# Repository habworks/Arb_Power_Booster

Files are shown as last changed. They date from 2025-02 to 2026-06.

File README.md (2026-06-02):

# Arbitrary Power Booster
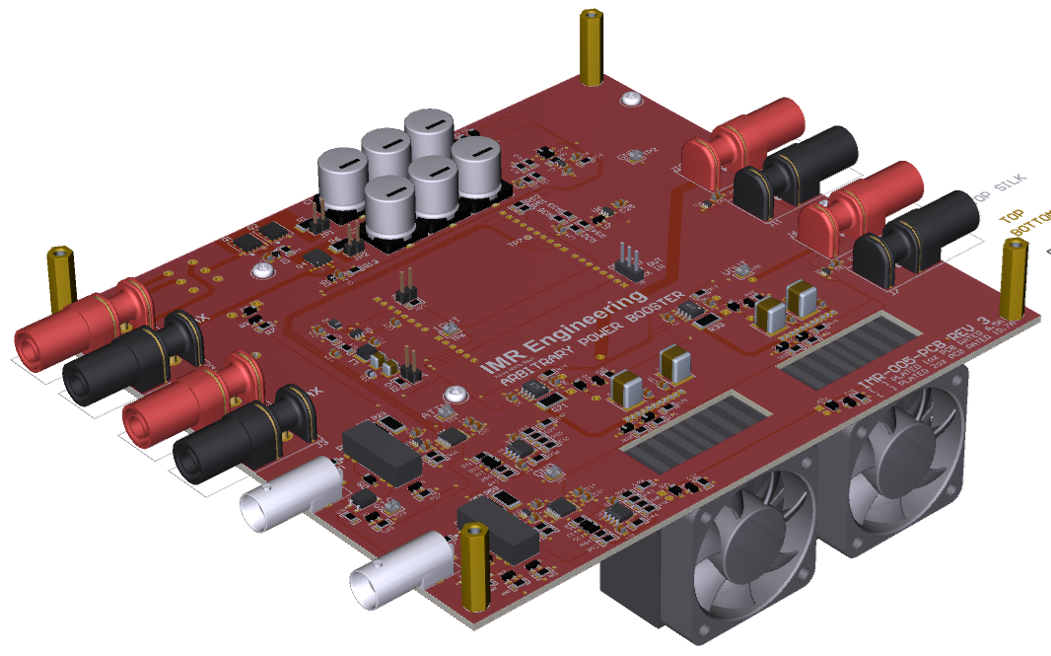
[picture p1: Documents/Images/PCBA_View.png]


## Quick Visual Links:
See [Video Demo](https://imrengineeringcom-my.sharepoint.com/:v:/g/personal/hab_collector_imrengineering_com/ETz-QbAvxjtEm_Lhyh-R2pUBUKSNs67Pcy3YFl8mtPB_mw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) from IMR Cloud<br>
See [User Manual & Technical Specification](https://imrengineeringcom-my.sharepoint.com/:b:/g/personal/hab_collector_imrengineering_com/EVBAl45Asp9Jv4Ho5CQpJLwBBzy_O8o_hFsLN9PBJ4WJYw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) from IMR Cloud<br>
See [Schematics PCB and BOM](https://imrengineeringcom-my.sharepoint.com/:b:/g/personal/hab_collector_imrengineering_com/EVWHgYOxN1xJqR7aqiF_OPgBgC4Y5v372JjiHFJdWcHM8w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) from IMR Cloud<br>

## Project Features:
Based on an ARM Cortex M7 two channel power amplication for driving heavy loads according to real world inputs.  Designed as a test equipment the device measures in True RMS with settable limits for power.  Features include:<br>
Hardware:
- 25W continuous per channel  
- Wide operating voltage -14V < Vo < +14V  
- Precision Absolute Value Divider  
- SSR Input Protection  
- Selectable Input Impedance  
- +/- Inrush Current Limiter  

Firmware:
- FreeRTOS OS  
- UI Touch Interface 242x480  
- True RMS  
- PID output control  
- Fault Tolerant  
- Smart Cooling  

Hardware and Firmware 100% designed by:<br>
Hab Collector<br>
Principal Engineer<br>
IMR Engineering, LLC<br>

## Project Folders:
| Folder | Description |
|---|---|
| Demo | URL to demo - just use the link provided above|
| Documents | UMTS, Images, and reference material|
| Firmware/ArbPwrBooster_App| Application Firmware|
| Hardware | Hardware Design in Circuit Studio: Schematics, PCB, BOM|
| Simulate | Spice Modle Simulation (LT Spice)|
| TestResults | Measured test results to support specification|

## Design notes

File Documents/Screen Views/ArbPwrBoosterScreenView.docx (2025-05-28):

ARBITRARY POWER BOOSTER SCREEN VIEWS

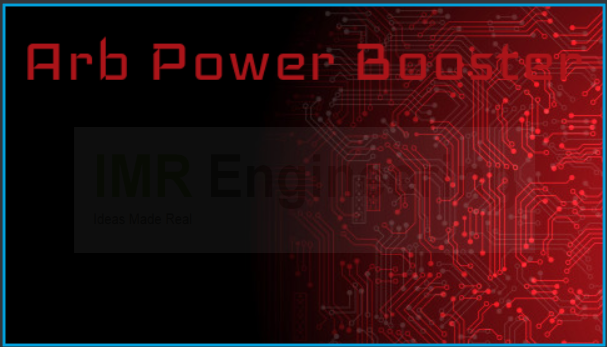
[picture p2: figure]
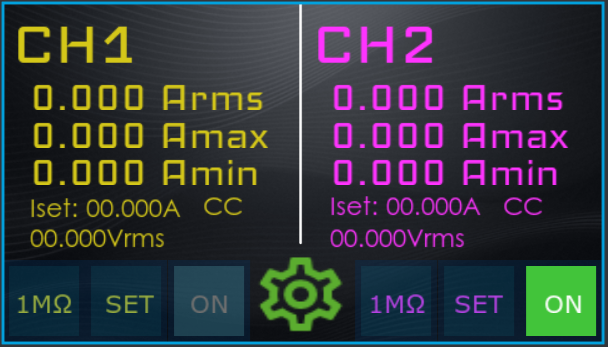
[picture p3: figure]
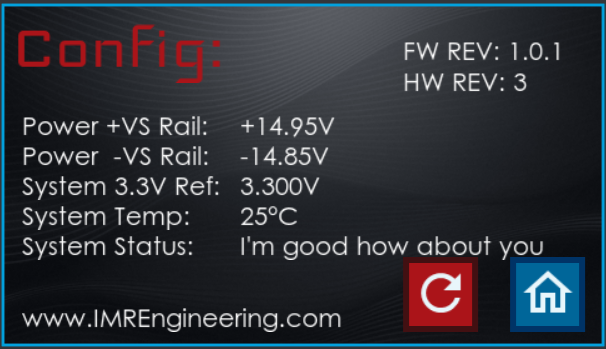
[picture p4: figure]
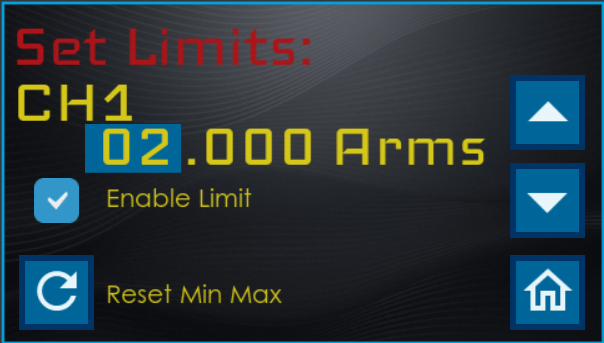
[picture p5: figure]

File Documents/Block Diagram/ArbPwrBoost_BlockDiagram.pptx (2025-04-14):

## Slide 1

MAIN PWR
RELAY

-15V INPUT

±15V PWR
MONITOR

- LAB SUPPLY 1
-15V NOMINAL

INRUSH
LIMITER

-20V INRUSH CURRENT LIMITER

BULK STORAGE

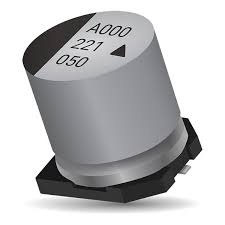
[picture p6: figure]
Aluminum Electrolytic Capacitors ...

-20V SWITCHED SUPPLY RAIL

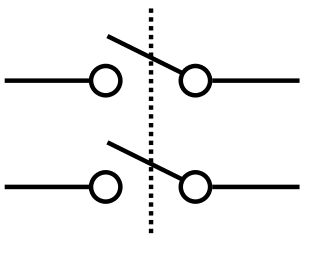
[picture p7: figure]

+15V INPUT

+ LAB SUPPLY 2
+15V NOMINAL

+20V INRUSH CURRENT LIMITER

+20V SWITCHED SUPPLY RAIL

5V REGULATOR
800mA

MAIN SUPPLY RAIL ENABLE

5V SYSTEM PWR

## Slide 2

CH1 IN

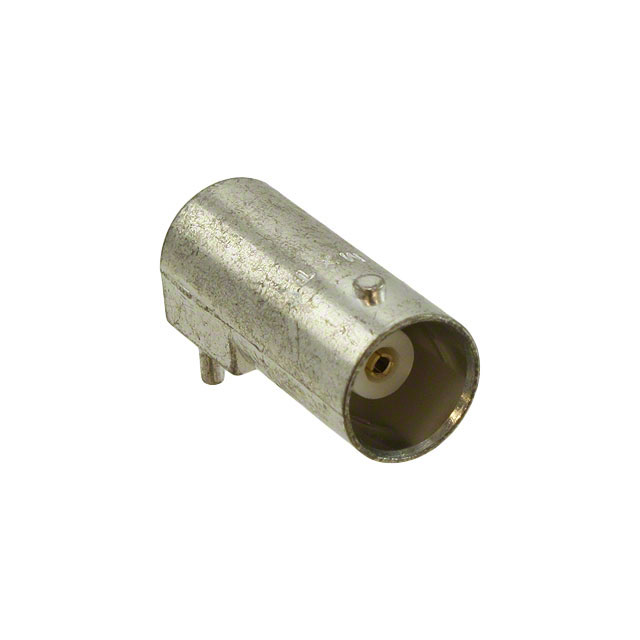
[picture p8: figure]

INPUT Z
SWITCHED
50Ω / 1MΩ

Av = 1

ADC ARB IN 1

DIGITAL
VOLTAGE
DIVIDER

Av = 1

+15V MON

Current
Boost

CURRENT
SENSE

OUTPUT
DISCONNECT

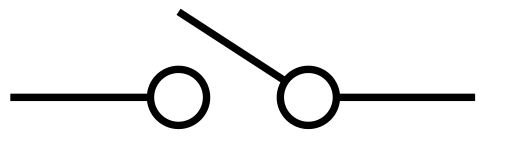
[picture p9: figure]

CH1 OUT

ADC – IMON 1

I2C

-15V MON

ADC

UI INTERFACE MODULE
STM32F746G-DISCO

ADC

3.3V SYSTEM PWR

CURRENT
SENSE

5V SYSTEM PWR

ADC – IMON 2

ADC ARB IN 2

Av = 1

DIGITAL
VOLTAGE
DIVIDER

I2C

INPUT Z
SWITCHED
50Ω / 1MΩ

Av = 1

Current
Boost

OUTPUT
DISCONNECT

CH2 IN

CH2 OUT

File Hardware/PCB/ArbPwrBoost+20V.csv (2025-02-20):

Index | X (mm) | Y (mm) | Arc Angle (Neg = CW)
0 | 74 | 159
1 | 144 | 159
2 | 144 | 17
3 | 55 | 17
4 | 50 | 17
3 | 29 | 17
5 | 29 | 38
6 | 125 | 38
7 | 125 | 61
8 | 29 | 61
9 | 29 | 79
10 | 50 | 79
11 | 55 | 79
12 | 125 | 79
13 | 125 | 147
14 | 74 | 147

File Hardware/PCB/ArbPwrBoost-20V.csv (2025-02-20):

Index | X (mm) | Y (mm) | Arc Angle (Neg = CW)
0 | 120 | 140
1 | 15 | 140
2 | 15 | 1
3 | 64 | 1
4 | 120 | 1
5 | 120 | 16
6 | 55 | 16
9 | 50 | 16
10 | 27.5 | 16
11 | 27.5 | 39
12 | 120 | 39
13 | 120 | 59.8
14 | 119.8 | 60
15 | 27.5 | 60
16 | 27.5 | 124
17 | 120 | 124

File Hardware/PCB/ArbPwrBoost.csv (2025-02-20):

Index | X (mm) | Y (mm) | Arc Angle (Neg = CW)
0 | 120 | 140
1 | 15 | 140
2 | 15 | 1
3 | 64 | 1
4 | 120 | 1
5 | 120 | 16
6 | 55 | 16
9 | 50 | 16
10 | 27.5 | 16
11 | 27.62 | 39
12 | 120 | 39
13 | 120 | 59.8
14 | 119.8 | 60
15 | 27.62 | 60
16 | 27.62 | 124
17 | 120 | 124

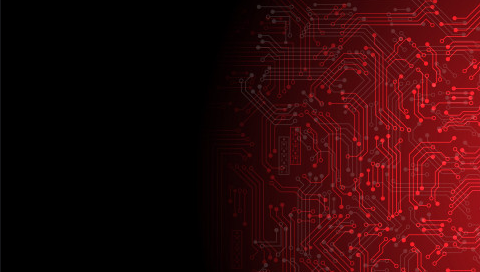
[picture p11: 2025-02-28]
Firmware/ArbPwrBooster_App/TouchGFX/assets/images/CircuitTrace_480x272.png

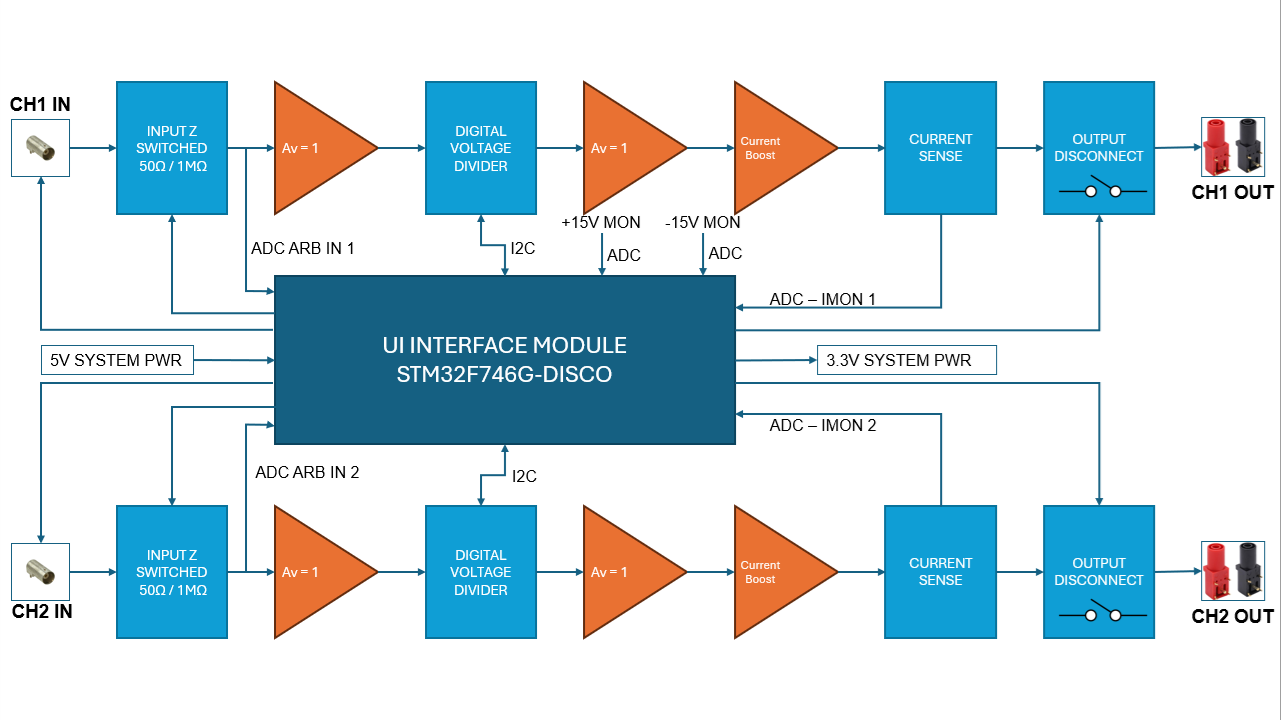
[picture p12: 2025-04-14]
Documents/Block Diagram/Block_PG2.png

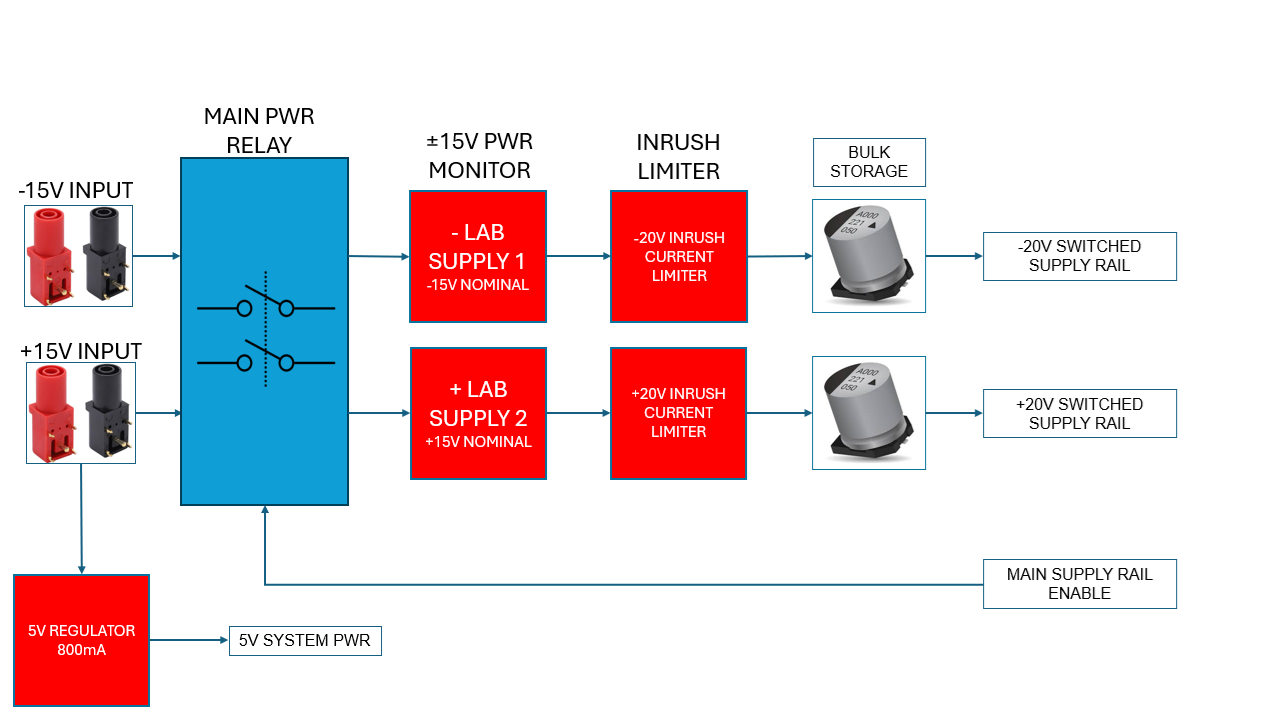
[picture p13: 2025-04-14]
Documents/Block Diagram/Block_PG1.png

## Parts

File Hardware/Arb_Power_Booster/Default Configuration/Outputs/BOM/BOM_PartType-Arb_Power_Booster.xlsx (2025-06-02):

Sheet: Part List Report
 |  | PROTOTYPE BOM |  |  | Arbitrary Power Booster
 |  | Source Data From: | Arb_Power_Booster.PrjPcb |  | Company Part Number: | IMR-005-SCH
 |  | Project: | Arb_Power_Booster.PrjPcb |  | PCB Revision: | 4
 |  | Variant: | None |  | Engineer: | Hab S Collector
 |  | Report Date: | 5/29/2025 | 9:01:38 AM
 |  | Print Date: | 2025-05-29 | 9:02:41
# | Quantity | LibRef | Description | Designator | MFG | MFG_PN | Supplier 1 | Supplier Part Number 1 | Unit Price | TOTAL
1 | 6 | CAP_330UF_50V_ALE | CAP ALE 330UF 20% 50V SMD | C1, C2, C3, C9, C10, C11 | EEV-FK1H331Q | Panasonic Electronic | DigiKey | PCE3475CT-ND | 1.41 | $8.46
2 | 3 | CAP_SMD_10UF_50V_0805 | CAP CER 10UF 50V X5R 0805 | C4, C12, C16 | Murata Electronics | GRM21BR61H106KE43L | DigiKey | 490-18663-1-ND | .28 | $0.84
3 | 30 | CAP_SMD_0.1UF_50V_0805 | CAP CER 0.1UF 50V X7R 0805 | C5, C6, C7, C8, C13, C17, C18, C19, C20, C21, C22, C23, C24, C25, C26, C27, C29, C33, C34, C35, C36, C37, C38, C39, C40, C41, C43, C44, C45, C46 | KYOCERA AVX | KGM21NR71H104KT | DigiKey | 478-KGM21NR71H104KTCT-ND | .1 | $3.00
4 | 1 | CAP_SMD_68PF_50V_0805 | CAP CER 68PF 50V X7R 0805 | C14 | KEMET | C0805C680K5RACAUTO | DigiKey | 399-C0805C680K5RACAUTOCT-ND | .24 | $0.24
5 | 2 | CAP_SMD_47UF_16V_1210 | CAP CER 47UF 50V X5R 1210 | C15, C48 | Murata Electronics | GRM32ER60J476ME20L | DigiKey | 490-1887-1-ND | .28 | $0.56
6 | 2 | CAP_SMD_1UF_50V_0805 | CAP CER 1UF 50V X7R 0805 | C28, C42 | KYOCERA AVX | 08055C105K4T2A | DigiKey | 478-KAM21KR71H105KUCT-ND | .27 | $0.54
7 | 4 | CAP_SMD_100UF_25V_SMD | CAP CER 100UF 25V X7S SMD | C30, C31, C32, C47 | Murata Electronics | KCM55WC71E107MH13L | DigiKey | 490-KCM55WC71E107MH13LCT-ND | 5.68 | $22.72
8 | 2 | DIODE_ZENER_MMSZ5239BS-7-F | DIODE ZENER 9.1V 200MW SOD323 | D1, D5 | Diodes Inc | MMSZ5239BS-7-F | DigiKey | MMSZ5239BS-FDICT-ND | .18 | $0.36
9 | 17 | DIODE_1N4148W-7-F | RELAY REED SPDT 250MA 5V | D2, D3, D7, D9, D10, D11, D12, D13, D14, D15, D16, D17, D18, D19, D20, D21, D22 | Diodes Inc | 1N4148W-7-F | DigiKey | 1N4148W-FDICT-ND | .16 | $2.72
10 | 2 | DIODE_SCHOTTKY_1N5819HW-7-F | DIODE SCHOTTKY 40V 1A SOD123 | D4, D8 | Diodes Inc | 1N5819HW-7-F | DigiKey | 1N5819HW-FDICT-ND | .25 | $0.50
11 | 1 | DIODE_SCHOTTKY_B240S1F-7 | DIODE SCHOTTKY 40V 2A SOD123F | D6 | Diodes Inc | B240S1F-7 | DigiKey | B240S1F-7DICT-ND | .25 | $0.25
12 | 2 | FAN_AFB0405LA-A | FAN AXIAL 40X10MM BALL 5VDC WIRE | FAN1, FAN2 | Delta Electronicis | AFB0405LA-A | DigiKey | 603-2014-ND | 7.31 | $14.62
13 | 1 | FERRITE_2508053017Y3 | FERRITE BEAD 300 OHM 0805 1LN | FB1 | Fair-Rite | 2508053017Y3 | DigiKey | 1934-1474-1-ND | .10 | $0.10
14 | 2 | HEATSINK_CS9464020BP | Heat Sink Aluminum Top Mount | HS1, HS2 | Cooling Source | CS9464020BP | DigiKey | 4165-CS9464020BP-ND | 3.41 | $6.82
15 | 4 | CONN_PANOMA_73099-2 | CONN 4mm Banana Socket Right Angle PCB RED | J1, J4, J6, J10 | Pomona | 73099-2 | DigiKey | 501-73099-2-ND | 10.39 | $41.56
16 | 4 | CONN_PANOMA_73099-0 | CONN 4mm Banana Socket Right Angle PCB BLK | J2, J3, J7, J11 | Pomona | 73099-0 | DigiKey | 501-73099-0-ND | 10.39 | $41.56
17 | 2 | CONN_MOLEX_0731713150 | CONN BNC RCPT R/A 50 OHM PCB | J5, J9 | Molex | 0731713150 | DigiKey | WM20430-ND | 1.40 | $2.80
18 | 1 | CONN_HEADER_3P_100MIL_VERT | CONN HEADER VERT 3POS 2.54MM | J8 | Sullins Connector Solutions | PREC003SFAN-RC | Digi-Key | S1212EC-03-ND | .07 | $0.07
19 | 4 | CONN_JUMPER_2P_100MIL_VERT | CONN HEADER VERT 2POS 2.54MM | JP1, JP2, JP3, JP4 | Sullins Connector Solutions | PREC002SFAN-RC | Digi-Key | S1212EC-02-ND | .07 | $0.28
20 | 1 | INDUCTOR_SRN4018TA-6R8M | FIXED IND 6.8UH 1.7A 98 MOHM SMD | L1 | Bourns Inc. | SRN4018TA-6R8M | DigiKey | SRN4018TA-6R8MCT-ND | .48 | $0.48
21 | 2 | LED_RED_LTST-C170EKT | LED RED CLEAR SMD | LED1, LED2 | Diodes Inc | LTST-C170EKT | DigiKey | 160-1178-1-ND | .18 | $0.36
22 | 8 | MECHANICAL_SCREW_M3X6_PAN_HEAD | SCREW M3X6 PAN HEAD SS | MECH1, MECH2, MECH3, MECH4, MECH9, MECH10, MECH11, MECH12 | APM Hexseal | RM3X6MM 2701 | DigiKey | 335-1156-ND | .58 | $4.64
23 | 4 | MECHANICAL_STANDOFF_M3X20 | HEX STANDOFF M3 BRASS 20MM | MECH5, MECH6, MECH7, MECH8 | Keystone Electronics | 24407 | DigiKey | 36-24407-ND | 1.36 | $5.44
24 | 2 | MOSFET_PCH_DMP6050SPS-13 | MOSFET P-CH 60V 5.7A PWRDI5060-8 | Q1, Q2 | Diodes Inc | DMP6050SPS-13 | DigiKey | DMP6050SPS-13DICT-ND | 1.07 | $2.14
25 | 7 | MOSFET_NCH_2N7002-7-F | MOSFET N-CH 60V 115MA SOT23-3 | Q3, Q7, Q8, Q9, Q10, Q11, Q12 | Diodes Inc | 2N7002-7-F | DigiKey | 2N7002-FDICT-ND | .20 | $1.40
26 | 1 | MOSFET_NCH_DMNH6042SPDQ-13 | MOSFET NCH 60V 5.7A POWERDI | Q4 | Diodes Inc | DMNH6042SPDQ-13 | DigiKey | DMNH6042SPDQ-13DICT-ND | 1.36 | $1.36
27 | 2 | MOSFET_NCH_DMN3023L-7 | MOSFET N-CH 30V 6.2A SOT23-3 | Q5, Q6 | Diodes Inc | DMN3023L-7 | DigiKey | DMN3023L-7DICT-ND | .48 | $0.96
28 | 2 | RES_SMD_0_2512_1W_1% | RES SMD 0 OHM 1% 1W 2512 | R1, R6 | Yageo | RC2512JK-070RL | DigiKey | YAG1232CT-ND | .2 | $0.40
29 | 18 | RES_SMD_10K_0805_1/4W_1% | RES SMD 10K OHM 1% 1/4W 0805 | R2, R7, R8, R25, R27, R30, R31, R32, R37, R38, R45, R51, R52, R63, R65, R66, R67, R69 | Yageo | RC0805FR-7W10KL | DigiKey | 13-RC0805FR-7W10KLCT-ND | .10 | $1.80
30 | 12 | RES_SMD_10K_0805_1/8W_0.1% | RES SMD 10K OHM 0.1% 1/8W 0805 | R3, R11, R42, R43, R46, R47, R53, R54, R61, R62, R64, R72 | Yageo | RP0805BRD0710KL | DigiKey | 13-RP0805BRD0710KLCT-ND | .16 | $1.92
31 | 2 | RES_SMD_47K_0805_1/8W_1% | RES SMD 47K OHM 1% 1/8W 0805 | R4, R13 | Yageo | RC0805FR-1347KL | DigiKey | 13-RC0805FR-1347KLCT-ND | .1 | $0.20
32 | 2 | RES_SMD_1.24K_0805_1/8W_0.1% | RES SMD 1.24K OHM 0.1% 1/8W 0805 | R5, R15 | Yageo | RT0805BRD071K24L | DigiKey | YAG1809CT-ND | .16 | $0.32
33 | 1 | RES_SMD_2.1K_0805_1/8W_0.1% | RES SMD 2.1K OHM 0.1% 1/8W 0805 | R9 | Yageo | RT0805BRD072K1L | DigiKey | YAG1852CT-ND | .16 | $0.16
34 | 8 | RES_SMD_0_0805_1/8W_1% | RES SMD 0 OHM 1% 1/8W 0805 | R10, R18, R19, R24, R26, R28, R36, R50 | Yageo | RC0805JR-070RL | DigiKey | 311-0.0ARCT-ND | .1 | $0.80
35 | 1 | RES_SMD_1.0K_0805_1/8W_0.1% | RES SMD 1.0K OHM 0.1% 1/8W 0805 | R12 | Yageo | RT0805BRD071KL | DigiKey | YAG1820CT-ND | .16 | $0.16
36 | 1 | RES_SMD_100K_0805_1/4W_1% | RES SMD 100K OHM 1% 1/4W 0805 | R14 | Yageo | RC0805FR-07100KL | DigiKey | 311-100KCRCT-ND | .13 | $0.13
37 | 1 | RES_SMD_1.0K_0805_1/8W_1% | RES SMD 1.0K OHM 1% 1/8W 0805 | R16 | Yageo | RC0805FR-071KL | DigiKey | 311-1.00KCRCT-ND | .1 | $0.10
38 | 1 | RES_SMD_12.4K_0805_1/8W_1% | RES SMD 12.4K OHM 1% 1/8W 0805 | R17 | Yageo | RC0805FR-0712K4L | DigiKey | 311-12.4KCRCT-ND | .10 | $0.10
39 | 2 | RES_SMD_300_0805_1/8W_1% | RES SMD 300 OHM 1% 1/8W 0805 | R20, R29 | Yageo | RC0805FR-07300RL | DigiKey | 311-300CRCT-ND | .1 | $0.20
40 | 2 | RES_SMD_1M_0805_1/4W_1% | RES SMD 1K OHM 1% 1/4W 0805 | R21, R57 | Yageo | RC0805FR-7W1ML | DigiKey | 13-RC0805FR-7W1MLCT-ND | .10 | $0.20
41 | 4 | RES_SMD_100_0805_3.5W_1% | RES SMD 100 OHM 1% 3.5W 2512 | R22, R23, R58, R59 | Ohmite | ALN2512F100RE-1 | DigiKey | 273-ALN2512F100RE-1CT-ND | 1.50 | $6.00
42 | 1 | RES_SMD_1.5K_0805_1/8W_0.1% | RES SMD 1.5K OHM 0.1% 1/8W 0805 | R33 | Yageo | RT0805BRD071K5L | DigiKey | YAG1814CT-ND | .16 | $0.16
43 | 1 | RES_SMD_4.7K_0805_1/8W_0.1% | RES SMD 4.7K OHM 0.1% 1/8W 0805 | R34 | Yageo | RT0805BRD074K7L | DigiKey | YAG1919CT-ND | .16 | $0.16
44 | 1 | RES_SMD_90.9_0805_1/8W_1% | RES SMD 90.9 OHM 1% 1/8W 0805 | R35 | Yageo | RC0805FR-0790R9L | DigiKey | 311-90.9CRCT-ND | .1 | $0.10
45 | 2 | RES_SMD_0.0065_2512_2W_1% | RES SMD 0.0065 OHM 1% 2W 2512 | R39, R71 | Vishay Dale | WSL25126L500FEA18 | DigiKey | 541-WSL25126L500FEA18CT-ND | 1.76 | $3.52
46 | 2 | RES_SMD_3.0K_0805_1/8W_0.1% | RES SMD 3.0K OHM 0.1% 1/8W 0805 | R40, R49 | Yageo | RT0805BRD073KL | DigiKey | YAG1891CT-ND | 0.16 | $0.32
47 | 2 | RES_SMD_4.99K_0805_1/8W_1% | RES SMD 4.99K OHM 1% 1/8W 0805 | R41, R48 | Yageo | RC0805FR-134K99L | DigiKey | 13-RC0805FR-134K99LCT-ND | .1 | $0.20
48 | 2 | RES_SMD_2.49K_0805_1/8W_1% | RES SMD 2.49K OHM 1% 1/8W 0805 | R44, R56 | Yageo | RC0805FR-132K49L | DigiKey | 13-RC0805FR-132K49LCT-ND | .1 | $0.20
49 | 2 | RES_SMD_5.0K_0805_1/8W_0.1% | RES SMD 5.0K OHM 0.1% 1/8W 0805 | R55, R68 | Yageo | AT0805BRD075KL | DigiKey | 13-AT0805BRD075KLCT-ND | .56 | $1.12
50 | 2 | RES_SMD_4.7K_0805_1/8W_1% | RES SMD 4.7K OHM 1% 1/8W 0805 | R60, R70 | Yageo | RC0805FR-134K7L | DigiKey | 13-RC0805FR-134K7LCT-ND | .1 | $0.20
51 | 2 | RES_SMD_10_0805_1/8W_1% | RES SMD 10 OHM 1% 1/8W 0805 | R73, R74 | Yageo | RC0805FR-1310RL | DigiKey | 13-RC0805FR-1310RLCT-ND | .1 | $0.20
52 | 1 | RELAY_AZ733-2AE-5DE | RELAY REED SPDT 250MA 5V | REL1 | American Zettler | AZ733-2AE-5DE | DigiKey | 3385-AZ733-2AE-5DE-nd | 2.18 | $2.18
53 | 2 | RELAY_HE721C0500 | RELAY REED SPDT 250MA 5V | REL2, REL4 | Littlefuse | HE721C0500 | DigiKey | HE112-ND | 3.77 | $7.54
54 | 2 | RELAY_G5LE-1-36 DC5 | RELAY GEN PURPOSE SPDT 10A 5V | REL3, REL5 | Omron | G5LE-1-36 DC5 | DigiKey | G5LE-1-36DC5-ND | 1.24 | $2.48
55 | 2 | RELAY_TLP170AM(TPL,E | SSR RELAY SPST-NO 700MA 0-60V | REL6, REL7 | Toshiba | TLP170AM(TPL,E | DigiKey | 264-TLP170AM(TPLECT-ND | 1.33 | $2.66
56 | 1 | SWITCH_SLW-12689-4A-N-D | SWITCH SLIDE SPDT 300MA 50V | SW1 | Same Sky | SLW-12689-4A-N-D | DigiKey | 2223-SLW-12689-4A-N-D-ND | .48 | $0.48
57 | 1 | SWITCH_EVQ-Q2U02W | SWITCH TACTILE SPST-NO 0.02A 15V | SW2 | American Zettler | EVQ-Q2U02W | DigiKey | P12954SCT-ND | .25 | $0.25
58 | 6 | CONN_TEST_POINT_S1751-46R | PCB TEST POINT CONNECT | TP1, TP2, TP3, TP4, TP5, TP6 | Harwin Inc | S1751-46R | Digi-Key | 952-1478-1-ND | .28 | $1.68
59 | 1 | IC_TPS54202DDCR | IC REG BUCK ADJ 2A SOT23 | U1 | Texas Instruments | TPS54202DDCR | Digi-Key | 296-TPS54202DDCRCT-ND | .97 | $0.97
60 | 3 | OPAMP_TLV9351IDCKR | IC OPAMP GP 3.5MHZ 350uV C70-5 | U2, U3, U10 | Texas Instruments | TLV9351IDCKR | DigiKey | 296-TLV9351IDCKRCT-ND | .49 | $1.47
61 | 2 | IC_MCP45HV51-104E/ST | IC DGT POT 100KOHM 256TP 14TSSOP | U4, U11 | Microchip | MCP45HV51-104E/ST | DigiKey | MCP45HV51-104E/ST-ND | 2.00 | $4.00
62 | 2 | IC_SN74LVC1G14DCKR | IC INVERT SCHMITT 1CH 1IN SC70-5 | U5, U16 | Texas Instruments | SN74LVC1G14DCKR | DigiKey | 296-11608-1-ND | .10 | $0.20
63 | 1 | OPAMP_LMP2011MFX/NOPB | IC OPAMP GP 3MHZ .12uV CIRCUIT SOT23-5 | U6 | Texas Instruments | LMP2011MFX/NOPB | DigiKey | LMP2011MFX/NOPBCT-ND | 2.33 | $2.33
64 | 1 | IC_LM4041CYM3-ADJ-TR | IC VREF SHUNT ADJ 0.5% SOT23-3 | U7 | Microchip | LM4041CYM3-ADJ-TR | DigiKey | 576-1049-1-ND | .39 | $0.39
65 | 2 | IC_INA282AIDR | IC CURRENT SENSE 0.4% 50V/V SOIC-8 | U8, U13 | Texas Instruments | INA282AIDR | DigiKey | 296-27820-1-ND | 4.13 | $8.26
66 | 1 | MODULE_STM32F746G-DISCO | DISCOVERY STM32 F7 EVAL BRD | U9 | ST Microlectronics | STM32F746G-DISCO | DigiKey | 497-15680-5-ND | 57.50 | $57.50
67 | 2 | OPAMP_OPA549S | IC OPAMP POWER 1 CIRC 11PWRPACK | U12, U17 | Texas Instruments | OPA549S | DigiKey | OPA549S-ND | 26.94 | $53.88
68 | 2 | OPAMP_TLV9302IDR | IC OPAMP GP 2 CIRCUIT 8SOIC | U14, U15 | Texas Instruments | TLV9302IDR | DigiKey | 296-53513-1-ND | .66 | $1.32
Approved |  |  |  |  | Notes |  |  | Bill of Cost (Unit Buy): |  | $331.04

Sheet: Project Information
Project Full Path | C:\IMR_Projects\IMR\Arb_Power_Booster\Hardware\Arb_Power_Booster\Arb_Power_Booster.PrjPcb
Project Filename | Arb_Power_Booster.PrjPcb
Variant Name | None
Data-Source Filename | Arb_Power_Booster.PrjPcb
Data-Source Full Path | C:\IMR_Projects\IMR\Arb_Power_Booster\Hardware\Arb_Power_Booster\Arb_Power_Booster.PrjPcb
Title | Arbitrary Power Booster
Total Quantity | 223
Report Time | 9:01:38 AM
Report Date | 5/29/2025
Report Date & Tine | 5/29/2025 9:01:38 AM
Output Name | BOM_PartType
Output Type | BOM_PartType
Output Generator Name | BOM
Output Generator Description | Bill of Materials
Total Actual Price | <Parameter TotalActualPrice not found>
Total Target Price | <Parameter TotalTargetPrice not found>

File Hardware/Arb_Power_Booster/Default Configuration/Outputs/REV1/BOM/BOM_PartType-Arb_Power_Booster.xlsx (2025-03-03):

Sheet: Part List Report
 |  | PROTOTYPE BOM |  |  | Arbitrary Power Booster
 |  | Source Data From: | Arb_Power_Booster.PrjPcb |  | Company Part Number: | IMR-005-SCH
 |  | Project: | Arb_Power_Booster.PrjPcb |  | PCB Revision: | 1
 |  | Variant: | None |  | Engineer: | Hab S Collector
 |  | Report Date: | 3/1/2025 | 7:32:12 AM
 |  | Print Date: | 2025-03-03 | 7:38:07
# | Quantity | LibRef | Description | Designator | MFG | MFG_PN | Supplier 1 | Supplier Part Number 1 | Unit Price | TOTAL
1 | 6 | CAP_330UF_50V_ALE | CAP ALE 330UF 20% 50V SMD | C1, C2, C3, C9, C10, C11 | EEV-FK1H331Q | Panasonic Electronic | DigiKey | PCE3475CT-ND | 1.41 | $8.46
2 | 3 | CAP_SMD_10UF_50V_0805 | CAP CER 10UF 50V X5R 0805 | C4, C12, C16 | Murata Electronics | GRM21BR61H106KE43L | DigiKey | 490-18663-1-ND | .28 | $0.84
3 | 26 | CAP_SMD_0.1UF_50V_0805 | CAP CER 0.1UF 50V X7R 0805 | C5, C6, C7, C8, C13, C17, C18, C19, C20, C21, C22, C23, C24, C25, C27, C28, C29, C33, C34, C35, C36, C37, C38, C39, C41, C42 | KYOCERA AVX | KGM21NR71H104KT | DigiKey | 478-KGM21NR71H104KTCT-ND | .1 | $2.60
4 | 1 | CAP_SMD_68PF_50V_0805 | CAP CER 68PF 50V X7R 0805 | C14 | KEMET | C0805C680K5RACAUTO | DigiKey | 399-C0805C680K5RACAUTOCT-ND | .24 | $0.24
5 | 1 | CAP_SMD_47UF_16V_1210 | CAP CER 47UF 50V X5R 1210 | C15 | Murata Electronics | GRM32ER60J476ME20L | DigiKey | 490-1887-1-ND | .28 | $0.28
6 | 2 | CAP_SMD_1UF_50V_0805 | CAP CER 1UF 50V X7R 0805 | C26, C40 | KYOCERA AVX | 08055C105K4T2A | DigiKey | 478-KAM21KR71H105KUCT-ND | .27 | $0.54
7 | 3 | CAP_SMD_100UF_25V_SMD | CAP CER 100UF 25V X7S SMD | C30, C31, C32 | Murata Electronics | KCM55WC71E107MH13L | DigiKey | 490-KCM55WC71E107MH13LCT-ND | 5.68 | $17.04
8 | 2 | DIODE_ZENER_MMSZ5239BS-7-F | DIODE ZENER 9.1V 200MW SOD323 | D1, D5 | Diodes Inc | MMSZ5239BS-7-F | DigiKey | MMSZ5239BS-FDICT-ND | .18 | $0.36
9 | 9 | DIODE_1N4148W-7-F | RELAY REED SPDT 250MA 5V | D2, D3, D7, D9, D10, D15, D16, D21, D22 | Diodes Inc | 1N4148W-7-F | DigiKey | 1N4148W-FDICT-ND | .16 | $1.44
10 | 1 | DIODE_ZENER_MMSZ5226BS-7-F | DIODE ZENER 3.3V 200MW SOD323 | D4 | Diodes Inc | MMSZ5226BS-7-F | DigiKey | MMSZ5226BS-FDICT-ND | .15 | $0.15
11 | 1 | DIODE_SCHOTTKY_1N5819HW-7-F | DIODE SCHOTTKY 40V 1A SOD123 | D6 | Diodes Inc | 1N5819HW-7-F | DigiKey | 1N5819HW-FDICT-ND | .25 | $0.25
12 | 1 | DIODE_ZENER_BZT52C2V0S-7-F | DIODE ZENER 2V 200MW SOD323 | D8 | Diodes Inc | BZT52C2V0S-7-F | DigiKey | BZT52C2V0S-7FDICT-ND | .15 | $0.15
13 | 8 | DIODE_ZENER_MMSZ5252BS-7-F | DIODE ZENER 24V 200MW SOD323 | D11, D12, D13, D14, D17, D18, D19, D20 | Diodes Inc | MMSZ5252BS-7-F | DigiKey | MMSZ5252BS-FDICT-ND | .12 | $0.96
14 | 4 | CONN_PANOMA_73099-2 | CONN 4mm Banana Socket Right Angle PCB RED | J1, J4, J6, J10 | Pomona | 73099-2 | DigiKey | 501-73099-2-ND | 10.39 | $41.56
15 | 4 | CONN_PANOMA_73099-0 | CONN 4mm Banana Socket Right Angle PCB BLK | J2, J3, J7, J11 | Pomona | 73099-0 | DigiKey | 501-73099-0-ND | 10.39 | $41.56
16 | 2 | CONN_MOLEX_0731713150 | CONN BNC RCPT R/A 50 OHM PCB | J5, J9 | Molex | 0731713150 | DigiKey | WM20430-ND | 1.40 | $2.80
17 | 1 | CONN_HEADER_3P_100MIL_VERT | CONN HEADER VERT 3POS 2.54MM | J8 | Sullins Connector Solutions | PREC003SFAN-RC | Digi-Key | S1212EC-03-ND | .07 | $0.07
18 | 10 | CONN_JUMPER_2P_100MIL_VERT | CONN HEADER VERT 2POS 2.54MM | JP1, JP2, JP3, JP4, JP5, JP6, JP7, JP8, JP9, JP10 | Sullins Connector Solutions | PREC002SFAN-RC | Digi-Key | S1212EC-02-ND | .07 | $0.70
19 | 1 | INDUCTOR_SRN4018TA-6R8M | FIXED IND 6.8UH 1.7A 98 MOHM SMD | L1 | Bourns Inc. | SRN4018TA-6R8M | DigiKey | SRN4018TA-6R8MCT-ND | .48 | $0.48
20 | 2 | MOSFET_PCH_DMP6050SPS-13 | MOSFET P-CH 60V 5.7A PWRDI5060-8 | Q1, Q2 | Diodes Inc | DMP6050SPS-13 | DigiKey | DMP6050SPS-13DICT-ND | 1.07 | $2.14
21 | 7 | MOSFET_NCH_2N7002-7-F | MOSFET N-CH 60V 115MA SOT23-3 | Q3, Q8, Q18, Q28, Q38, Q45, Q46 | Diodes Inc | 2N7002-7-F | DigiKey | 2N7002-FDICT-ND | .20 | $1.40
22 | 1 | MOSFET_NCH_DMNH6042SPDQ-13 | MOSFET NCH 60V 5.7A POWERDI | Q4 | Diodes Inc | DMNH6042SPDQ-13 | DigiKey | DMNH6042SPDQ-13DICT-ND | 1.36 | $1.36
23 | 8 | BJT_PNP_2SAR582D3FRATL | TRANS PNP 30V 5.7A TO-252 | Q5, Q12, Q13, Q14, Q25, Q32, Q33, Q34 | Rohm Semiconductor | 2SAR582D3FRATL | DigiKey | 846-2SAR582D3FRATLCT-ND | 1.59 | $12.72
24 | 10 | BJT_NPN_MMBT4401LT1G | TRANS NPN 40V 0.6A SOT23-3 | Q6, Q9, Q15, Q16, Q17, Q26, Q29, Q35, Q36, Q37 | On Semiconductor | MMBT4401LT1G | DigiKey | MMBT4401LT1GOSCT-ND | .13 | $1.30
25 | 10 | BJT_PNP_MMBT4403LT1G | TRANS PNP 40V 0.6A SOT23-3 | Q7, Q10, Q19, Q20, Q21, Q27, Q30, Q39, Q40, Q41 | On Semiconductor | MMBT4403LT1G | DigiKey | MMBT4403LT1GOSCT-ND | .13 | $1.30
26 | 8 | BJT_NPN_2SCR582D3FRATL | TRANS NPN 30V 10A TO-252 | Q11, Q22, Q23, Q24, Q31, Q42, Q43, Q44 | Rohm Semiconductor | 2SCR582D3FRATL | DigiKey | 846-2SCR582D3FRATLCT-ND, 846-2SCR582D3FRATLCT-ND, 846-2SCR582D3FRATLCT-ND, 846-2SCR582D3FRATLCT-ND, 849-2SCR582D3FRATL-ND, 846-2SCR582D3FRATLCT-ND, 846-2SCR582D3FRATLCT-ND, 846-2SCR582D3FRATLCT-ND | 1.76 | $14.08
27 | 2 | RES_SMD_0_2512_1W_1% | RES SMD 0 OHM 1% 1W 2512 | R1, R6 | Yageo | RC2512JK-070RL | DigiKey | YAG1232CT-ND | .2 | $0.40
28 | 27 | RES_SMD_10K_0805_1/4W_1% | RES SMD 10K OHM 1% 1/4W 0805 | R2, R3, R7, R8, R11, R16, R27, R30, R31, R32, R45, R46, R47, R48, R49, R51, R52, R63, R66, R67, R77, R78, R79, R80, R81, R82, R83 | Yageo | RC0805FR-7W10KL | DigiKey | 13-RC0805FR-7W10KLCT-ND | .10 | $2.70
29 | 2 | RES_SMD_47K_0805_1/8W_1% | RES SMD 47K OHM 1% 1/8W 0805 | R4, R13 | Yageo | RC0805FR-1347KL | DigiKey | 13-RC0805FR-1347KLCT-ND | .1 | $0.20
30 | 2 | RES_SMD_1.24K_0805_1/8W_1% | RES SMD 1.24K OHM 1% 1/8W 0805 | R5, R15 | Yageo | RC0805FR-071K24L | DigiKey | 311-1.24KCRCT-ND | .1 | $0.20
31 | 1 | RES_SMD_2.1K_0805_1/8W_1% | RES SMD 2.1K OHM 1% 1/8W 0805 | R9 | Yageo | RC0805FR-072K1L | DigiKey | 311-2.10KCRCT-ND | .1 | $0.10
32 | 7 | RES_SMD_0_0805_1/8W_1% | RES SMD 0 OHM 1% 1/8W 0805 | R10, R20, R26, R50, R53, R56, R62 | Yageo | RC0805JR-070RL | DigiKey | 311-0.0ARCT-ND | .1 | $0.70
33 | 1 | RES_SMD_1.0K_0805_1/8W_1% | RES SMD 1.0K OHM 1% 1/8W 0805 | R12 | Yageo | RC0805FR-071KL | DigiKey | 311-1.00KCRCT-ND | .1 | $0.10
34 | 1 | RES_SMD_100K_0805_1/4W_1% | RES SMD 100K OHM 1% 1/4W 0805 | R14 | Yageo | RC0805FR-07100KL | DigiKey | 311-100KCRCT-ND | .13 | $0.13
35 | 1 | RES_SMD_13.7K_0805_1/8W_1% | RES SMD 13.7K OHM 1% 1/8W 0805 | R17 | Yageo | RC0805FR-0713K7L | DigiKey | 311-13.7KCRCT-ND | .10 | $0.10
36 | 8 | RES_SMD_100_0805_3.5W_1% | RES SMD 100 OHM 1% 3.5W 2512 | R18, R19, R22, R23, R54, R55, R58, R59 | Ohmite | ALN2512F100RE-1 | DigiKey | 273-ALN2512F100RE-1CT-ND | 1.50 | $12.00
37 | 2 | RES_SMD_1M_0805_1/4W_1% | RES SMD 1K OHM 1% 1/4W 0805 | R21, R57 | Yageo | RC0805FR-7W1ML | DigiKey | 13-RC0805FR-7W1MLCT-ND | .10 | $0.20
38 | 16 | RES_SMD_0.1_1206_1/4W_1% | RES SMD 0.1 OHM 1% 1/4W 1206 | R24, R25, R36, R37, R38, R40, R41, R42, R60, R61, R68, R69, R70, R72, R73, R74 | Yageo | 311-0.1LWCT-ND | DigiKey | 311-100KCRCT-ND | .45 | $7.20
39 | 2 | RES_SMD_240_2512_3W_5% | RES 240 OHM 5% 3W 2512 | R28, R64 | Yageo | RC2512JK-07240RL | DigiKey | 13-RC2512JK-07240RLCT-ND | .28 | $0.56
40 | 2 | RES_SMD_270_2512_3W_5% | RES 270 OHM 5% 1W 2512 | R29, R65 | Yageo | RC2512JK-07270RL | DigiKey | 13-RC2512JK-07270RLCT-ND | .21 | $0.42
41 | 1 | RES_SMD_1.58K_0805_1/8W_1% | RES SMD 1.58K OHM 1% 1/8W 0805 | R33 | Yageo | RC0805FR-071K58L | DigiKey | 311-1.58KCRCT-ND | .1 | $0.10
42 | 1 | RES_SMD_4.7K_0805_1/8W_1% | RES SMD 4.7K OHM 1% 1/8W 0805 | R34 | Yageo | RC0805FR-134K7L | DigiKey | 13-RC0805FR-134K7LCT-ND | .1 | $0.10
43 | 1 | RES_SMD_100_0805_1/8W_1% | RES SMD 100 OHM 1% 1/8W 0805 | R35 | Yageo | RC0805FR-07100RL | DigiKey | 311-100CRCT-ND | .1 | $0.10
44 | 2 | RES_SMD_0.0033_2512_3W_1% | RES SMD 0.0033 OHM 1% 3W 2512 | R39, R71 | Vishay Dale | WSLP25123L300FEA | DigiKey | 541-10151-1-ND | 1.23 | $2.46
45 | 4 | RES_SMD_10_0805_1/8W_1% | RES SMD 10 OHM 1% 1/8W 0805 | R43, R44, R75, R76 | Yageo | RC0805FR-1310RL | DigiKey | 13-RC0805FR-1310RLCT-ND | .1 | $0.40
46 | 1 | RELAY_AZ733-2AE-5DE | RELAY REED SPDT 250MA 5V | REL1 | American Zettler | AZ733-2AE-5DE | DigiKey | 3385-AZ733-2AE-5DE-nd | 2.18 | $2.18
47 | 2 | RELAY_HE721C0500 | RELAY REED SPDT 250MA 5V | REL2, REL4 | Littlefuse | HE721C0500 | DigiKey | HE112-ND | 3.77 | $7.54
48 | 2 | RELAY_G5LE-1-36 DC5 | RELAY GEN PURPOSE SPDT 10A 5V | REL3, REL5 | Omron | G5LE-1-36 DC5 | DigiKey | G5LE-1-36DC5-ND | 1.24 | $2.48
49 | 2 | RELAY_TLP170AM(TPL,E | SSR RELAY SPST-NO 700MA 0-60V | REL6, REL7 | Toshiba | TLP170AM(TPL,E | DigiKey | 264-TLP170AM(TPLECT-ND | 1.33 | $2.66
50 | 1 | SWITCH_SLW-12689-4A-N-D | SWITCH SLIDE SPDT 300MA 50V | SW1 | Same Sky | SLW-12689-4A-N-D | DigiKey | 2223-SLW-12689-4A-N-D-ND | .48 | $0.48
51 | 1 | SWITCH_EVQ-Q2U02W | SWITCH TACTILE SPST-NO 0.02A 15V | SW2 | American Zettler | EVQ-Q2U02W | DigiKey | P12954SCT-ND | .25 | $0.25
52 | 8 | CONN_TEST_POINT_S1751-46R | PCB TEST POINT CONNECT | TP1, TP2, TP3, TP4, TP5, TP6, TP11, TP12 | Harwin Inc | S1751-46R | Digi-Key | 952-1478-1-ND | .28 | $2.24
53 | 1 | IC_TPS54202DDCR | IC REG BUCK ADJ 2A SOT23 | U1 | Texas Instruments | TPS54202DDCR | Digi-Key | 296-TPS54202DDCRCT-ND | .97 | $0.97
54 | 5 | OPAMP_TLV9351IDCKR | IC OPAMP GP 3.5MHZ 350uV C70-5 | U2, U3, U5, U10, U12 | Texas Instruments | TLV9351IDCKR | DigiKey | 296-TLV9351IDCKRCT-ND | .49 | $2.45
55 | 2 | IC_MCP45HV31-104E/ST | IC DGT POT 100KOHM 128TP 14TSSOP | U4, U11 | Microchip | MCP45HV31-104E/ST | DigiKey | MCP45HV31-104E/ST-ND | 1.82 | $3.64
56 | 1 | OPAMP_LMP2011MFX/NOPB | IC OPAMP GP 3MHZ .12uV CIRCUIT SOT23-5 | U6 | Texas Instruments | LMP2011MFX/NOPB | DigiKey | LMP2011MFX/NOPBCT-ND | 2.33 | $2.33
57 | 1 | IC_LM4041CYM3-ADJ-TR | IC VREF SHUNT ADJ 0.5% SOT23-3 | U7 | Microchip | LM4041CYM3-ADJ-TR | DigiKey | 576-1049-1-ND | .39 | $0.39
58 | 2 | IC_INA199A1DCKR | IC CURRENT SENSE 1.5% 50V/V SC70-6 | U8, U13 | Texas Instruments | INA199A1DCKR | DigiKey | 296-27329-1-ND | .45 | $0.90
59 | 1 | MODULE_STM32F746G-DISCO | DISCOVERY STM32 F7 EVAL BRD | U9 | ST Microlectronics | STM32F746G-DISCO | DigiKey | 497-15680-5-ND | 57.50 | $57.50
Approved |  |  |  |  | Notes |  |  | Bill of Cost (Unit Buy): |  | $268.96

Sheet: Project Information
Project Full Path | C:\IMR_Projects\IMR\Arb_Power_Booster\Hardware\Arb_Power_Booster\Arb_Power_Booster.PrjPcb
Project Filename | Arb_Power_Booster.PrjPcb
Variant Name | None
Data-Source Filename | Arb_Power_Booster.PrjPcb
Data-Source Full Path | C:\IMR_Projects\IMR\Arb_Power_Booster\Hardware\Arb_Power_Booster\Arb_Power_Booster.PrjPcb
Title | BOM_PartType For Project [Arb_Power_Booster.PrjPcb] (No PCB Document Selected)
Total Quantity | 245
Report Time | 7:32:12 AM
Report Date | 3/1/2025
Report Date & Tine | 3/1/2025 7:32:12 AM
Output Name | BOM_PartType
Output Type | BOM_PartType
Output Generator Name | BOM
Output Generator Description | Bill of Materials
Total Actual Price | <Parameter TotalActualPrice not found>
Total Target Price | <Parameter TotalTargetPrice not found>

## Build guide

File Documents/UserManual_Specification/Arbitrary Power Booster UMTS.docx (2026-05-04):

ARBITRARY POWER BOOSTER

IMR Engineering, LLC

Ideas Made Real

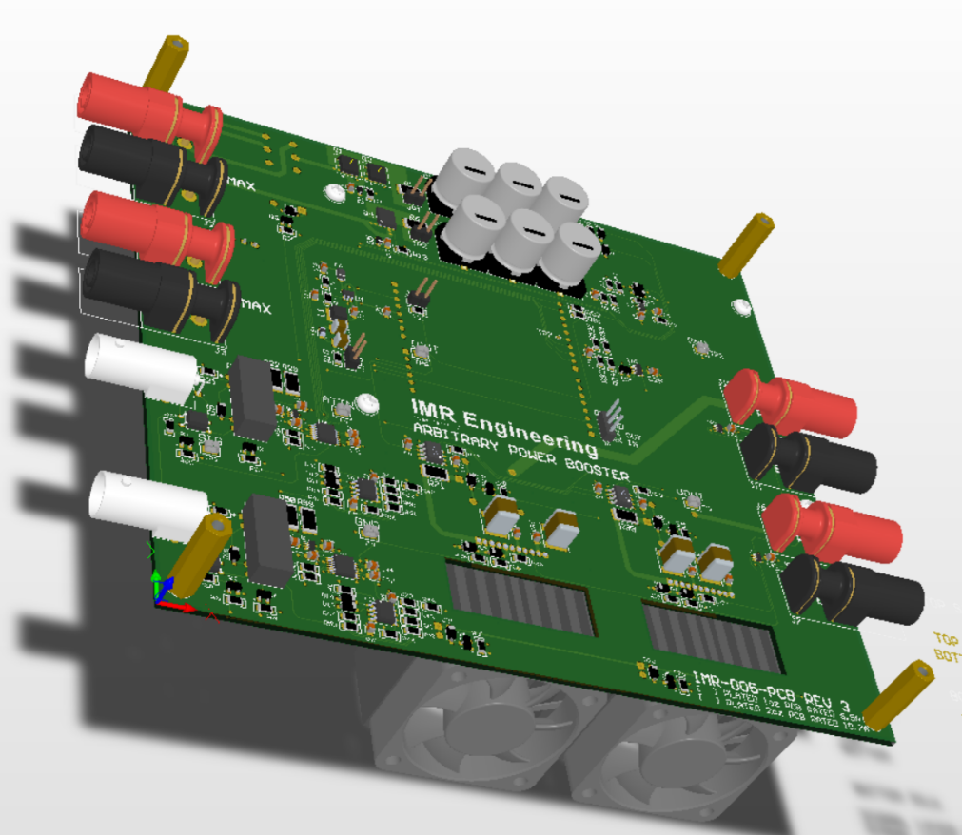
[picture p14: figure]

USER MANUAL AND TECHNICAL SPECIFICATION

Principal Engineer: Hab Collector

http://imrengineering.com

DOCUMENT REVISION HISTORY
DATE | DESCRIPTION | EDIT BY
2025-05-29 | Initial draft - Preliminary | HSC
2025-05-30 | Minor formatting. Thermal image clarification. Some additional verbiage for clarity. | HSC
2025-06-03 | Correction to accuracy statement | HSC
2025-06-07 | Amendment to acknowledgement | HSC

# 1. INTRODUCTION:

## 1.1 THE PROBLEM:

Your embedded device is part of a much larger system, a system that does not live in isolation, and neither does its power source. It receives power from a parent platform: a drone, a vehicle, modular device, or trailer. While you may have scoped the rails for ripple and noise, what you are really up against is something much harder to simulate and, in fact, more impactful on your embedded DUT.

The power it receives is corrupted; not by the high-frequency harmonic noise you already know how to filter out, but by a deeper, more erratic class of disturbance: harmonic brownouts, surge events, and at times regenerative effects from inductive kickback or back-fed energy. These conditions aren’t artifacts. They are systemic and the reason your device does not operate optimally. This supply rail issue manifests itself in multiple ways:

- Unwanted reset conditions
- Incorrect ADC or DAC measurements or conversions
- Destroyed components or components operating outside specification
- Improper charging or failure to charge
- Etc.

Though it works perfectly on the bench, it fails in-system. The truth is, your benchtop power supply, clean uninterrupted power, is anything but real world. It’s clean, linear, obedient nature in such use-cases only masks the problem. As an engineer it is always your problem to solve, and so you are left with a simple but painful truth: the only place to test and debug these conditions is in the system, in the field, and in person. It cannot be debugged and tested remotely. Or can it?

## 1.2 THE WHAT IF:

Imagine sending your device a: sensor node, data collector, motor controller, or custom SoC board to a client site, a co-developer, or even a third-party integrator. Not waiting for them to integrate, test, and describe what happens under load. From your computer. In your lab. You replicate the exact issue the system imposes on the DUT. And what if you could scale that – not just a single supply rail or source signal, but multiple, and multiple DUT.

Imagine every prototype being powered by a small, intelligent, software-controlled power source that mimics system source issues exactly as they are, on your bench, in your lab, in real time, with real debug and test. Imagine a company standard for supply rail disturbances every embedded device must pass.

Not a luxury - a competitive edge.

## 1.3 THE SOLUTION:

The Arbitrary Power Booster (APB) from IMR Engineering is a precision, high-current, microcontroller-controlled voltage source designed to solve exactly this problem. It acts as a downstream power amplifier, taking in a programmable waveform from an Arbitrary Waveform Generator (AWG) and amplifying that signal into a high-current output — all while regulating the voltage and enforcing programmable current limits in real-time. Why an AWG? Because we are not trying to reinvent the wheel, but solve a real problem in a real way. The AWG is already on your desk. AWGs have the ability to accept and output raw data oscilloscope captures, complex math functions, or scripted sequences. The Arbitrary Power Booster does the rest.

At its core, the Arb Power Booster enables remote, scriptable, and repeatable testing with real load conditions. Its firmware integrates a closed-loop feedback system that monitors output current and enforces soft limits via a firmware-defined PID response. From an engineering perspective, it is a drop-in test solution for hardware developers. From a business perspective, it is a scalable tool for remote debugging, client demos, and iterative remote design. Work done anywhere from everywhere - in this digital age. That is not our future, that is today. That is how we work. The Arb Power Booster adds to that world. I trust you will find it a helpful tool. Ideas Made Real.

# 2. AT A GLANCE:

## 2.1 FEATURES:

- Real Time True RMS measure on current and voltage
- PID constant current limit
- Selectable 1MΩ or 50Ω input impedance
- 109.2mm Color LCD Display with 16b color depth
- 480x242 Pixel with Touch LCD HMI
- SSR Fault tolerant Input isolation and protection
- Fault supply rail disconnect
- Device Inrush current limiter
- Over temperature shutdown indicators
- Smart Fan cooling
- uSD user parameter storage
- ARM Cortex M7 200MHz
- Dual independent channel control
- Over Temperature shutdown
- Over Temperature LED indication

## 2.2 APPLICATIONS:

- Augmented Test Equipment
- Remote source simulation
- Supply rail hardening
- Debug Test Develop and Deploy from anywhere

## 2.3 SIMPLIFIED BLOCK DIAGRAM

# 3. MODES OF OPERATION:

The Arb Power Booster has a simple, and intuitive 4 screen interface.

- Splash Screen
- Main Screen
- Configuration Screen
- Set Limits Screen

## 3.1 SPLASH SCREEN:

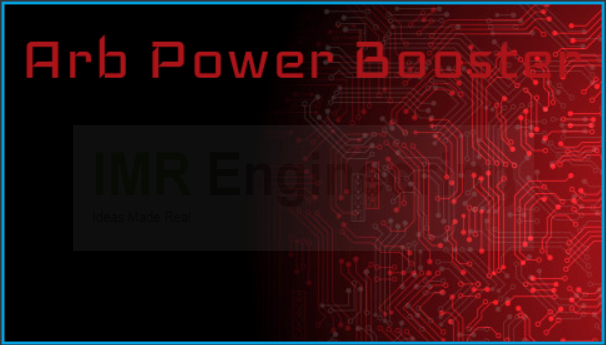
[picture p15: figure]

Prompted by POR (Power On Reset) the device is operational with the display of the introduction / splash screen. Following the introduction screen a test of the system parameters to include:

- System ±Supply Rails
- System 3.3V tolerance
- Junction Temperature

is conducted and the Main Screen is launched.

## 3.2 MAIN SCREEN:


READINGS:

The main screen shows measurement and control for both channels. Output current in RMS, min, and max instantaneous current. If enabled, The set current limit (Iset) and if active, Constant Current (CC) indicator (next to the set current limit). Lastly, the supplied signal in volts RMS. NOTE if the current limit is enabled and the device is in Constant Current mode both the CC indicator and the RMS voltage will flash. The RMS voltage when in CC mode will reflect the actual output value feed to the load and not the input.

CONTROL:

Input Impedance:

The far-left button controls the input impedance. It will read either 1MΩ or 50Ω depending on what it is currently set to. It is a toggle action. This load is the input impedance to the AWG output.

Set:

The middle control. This selection will launch the set limits screen

On:

This is the output on / off control. Note the button only reads “ON”. The background color gives context. When the output is disabled (switched off) it will appear as the channel 1 indicator pictured above. When the output is enabled (switched on) it will appear as the channel 2 indicator. Fan on / off control is firmware driven – on when power dissipated by the output amplifier is greater than 3.5W and truns off 30s following the reduction of this value.

Gear:

The gear is the system status indicator. If green (as shown) it indicates all system parameters are within the specified tolerances. If highlighted by a red box then one or more system parameters are outside the specified tolerances and a system status correction is given. Selecting this control will launch the configuration screen.

## 3.3 CONFIG SCREEN:


Reset:

This is the red “re-do” button. Selection will cause a device reset – it is disabled in the present revision of firmware – future use TBD.

Home:

Return to the Main Screen

## 3.4 SET LIMITS SCREEN:


Current Limit:

The current limit is set by selecting the desired Amps, tenths of amps, hundredths of amps, or thousands of amps control. On selection each measure can be incremented up or down via the up / down controls. Note the current limit can not be changed unless Enable Limit is selected.

Enable Limit

Check box, when checked CC mode is enabled via PID control to the current limit

Reset Min Max

Reset the present min and max and return to the Main Screen

Home

Return to Main Screen

## 3.5 PHYSICAL CONTROLS:

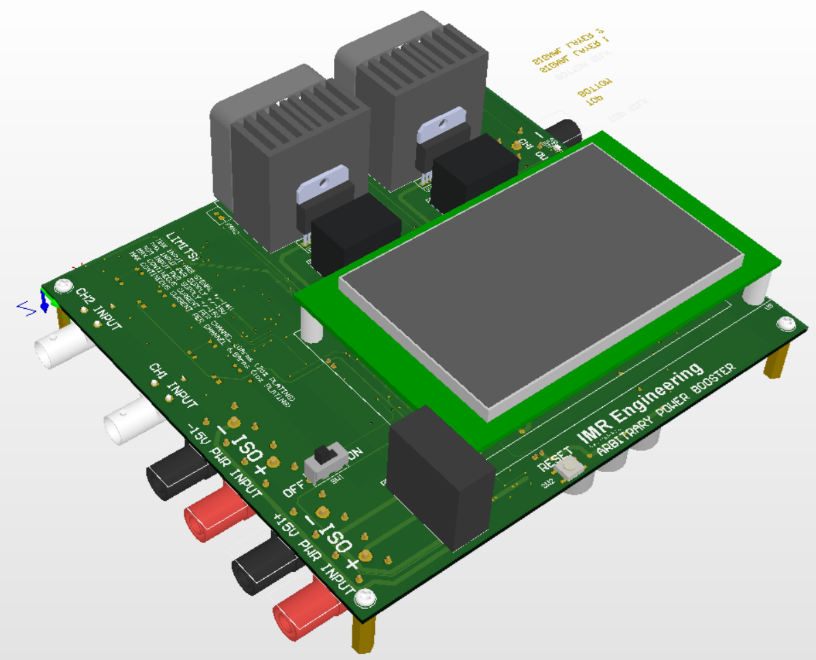
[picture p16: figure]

- ON / OFF slide control
- RESET (POR) momentary push tactile

# 4. TECHNICAL SPECIFICATIONS:

## 4.1 MEASURES

ABSOLUTE MAX RATINGS
PARAMETER | CONDITION | Min | Typ | Max | UNIT

ENVIRONMENTAL
Operating Temperature | | -20 | | 30 | oC
Storage Temperature | | -40 | | 85 | oC
Relative Humidity | Non-condensing | | | 97 | %

SUPPLY RAIL INPUTS
+VS Supply rail | As measured at the APB | 14.5 | 15.0 | 15.5 | V
-VS Supply rail | | -15.5 | -15.0 | -14.5 | V

INPUT
Input | | 0 | | 14.3 | V

OPERATIONAL SPECIFICATIONS
PARAMETER | CONDITION | Min | Typ | Max | UNIT

ENVIRONMENTAL
Temperature | | -20 | | 30 | oC
Relative Humidity | Non-condensing | 0 | | 95 | %

PHYSICAL DIMENSIONS
Length | | | 160.0 | | mm
Width | Does not include connectors | | 180.0 | | mm
Height | Lowest to highest measure | | 62.0 | | mm

INPUT
Impedance | 1% of 1MΩ or 50Ω | | | | Ω
Voltage Range | | -14 | | 14 | V
Voltage Measure (Reading) | Measured as % Vrms | -0.5 | | +0.5 | %

OUTPUT
Gain | ¹Non unity gain during CC mode | | 1 | 1 | V/V
Peak Current | ²Not max power | | | 10 | A
Continuous Current | ²Not max power | | | 8 | A
Peak Power | Max peak time 5s at Ambient 25°C | | | 60 | W
Continuous | Ambient 25°C | | | 25 | W
Current Measure (Reading) Iout = Output Current | ⁴ Iout > 100mArms to limit ⁴ 30mA < Iout < 100mArms ⁴ Below 30mArms no statement | -1.0 -10m NA | NA | +1.0 +10m NA | % Arms

POWER CONSUMPTION
Load on -VS supply rail | ³No output loading | | | -10 | mA
Load on +VS supply rail | ³No output loading | | | 330 | mA
Switch in OFF position | | | | 45 | µA

FREQUENCY AND SAMPLE RATE
Input frequency range | | 0 | | 7.812 | KHz
Sample Rate ±VS, Vin, Output Amps | | | 64.00 | | µs
Sample Rate 3.3V & Temperature | | | 71.11 | | µs

CONSTANT CURRENT MODE
Time to 95% convergence CC | | | | 310 | ms
Time to CC mode deactivated | Removal of fault load | | | 200 | ms

NOTES:

¹In constant current mode the gain is adjusted in steps via 256 steps from unity to with the first non unity gain decreasing occurring at 0.9961V/V and the last at incremental step at 0.0039V/V

²Output power is limited by the ability to dissipate heat to keep the output amplifiers junction temperature below 160°C. The amplifier’s dissipated power can be approximated by the equation: (Vs nominal – Output Voltage) x Output Current

³±VS nominal supply. Output to both channels switched on. Both fans are on. Input impedance both channels set to 50Ω. There is no output load.

⁴Below 30mArms current what is displayed is the mean not RMS current. Two different ranges for accuracy are given, below and above 100mArms.

## 4.2 ±VS CURRENT INRUSH MEASURE

+VS Current Inrush Measure

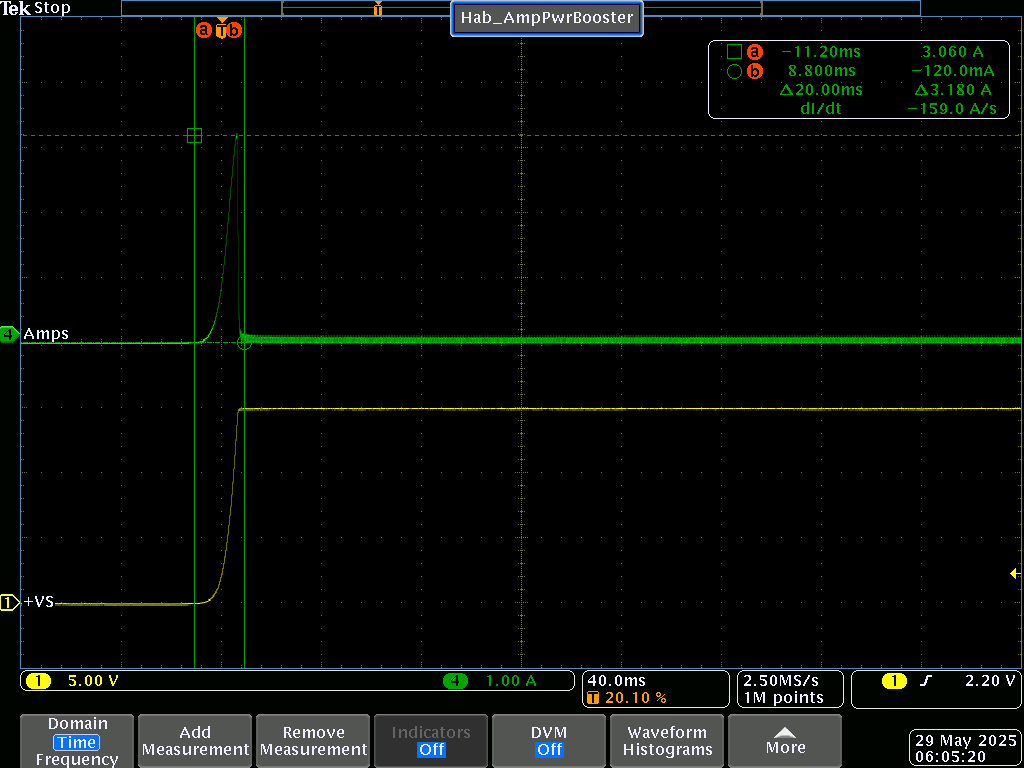
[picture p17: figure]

- As measured at POR (Power On Reset)
- NO OUTPUT LOAD

-VS Current Inrush Measure

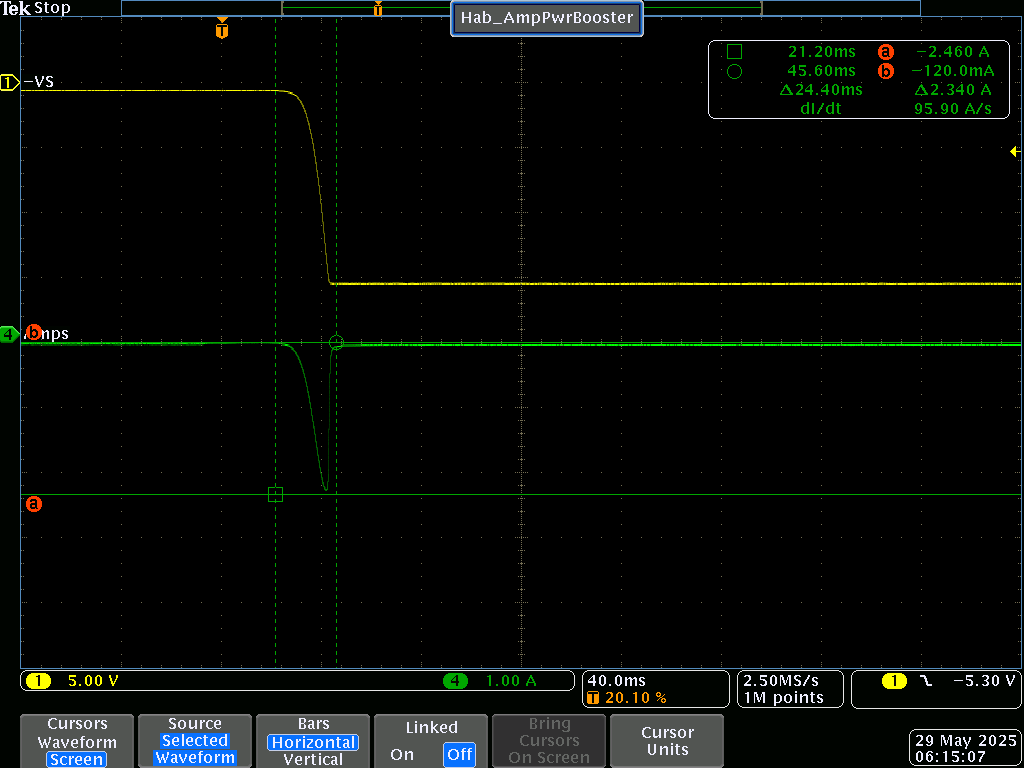
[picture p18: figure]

- As measured at POR (Power On Reset)
- NO OUTPUT LOAD

## 4.3 INPUT TO OUTPUT 5KHz LOADED AND UNLOADED

Input Output Response 5KHz No Load

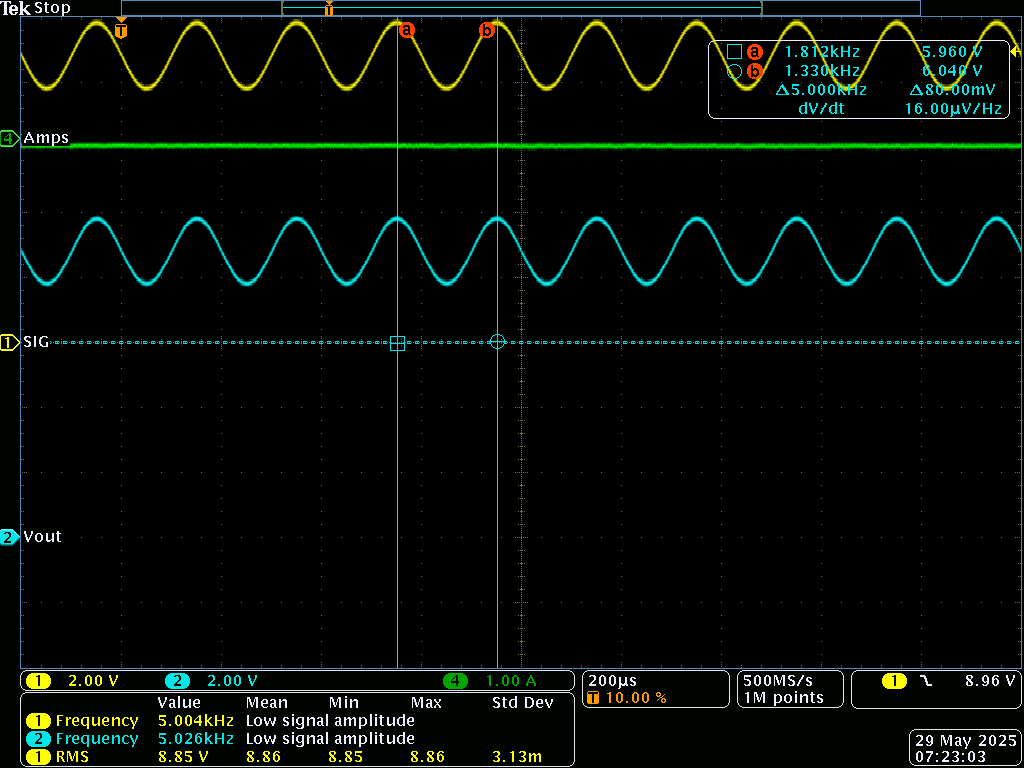
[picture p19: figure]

- No measurable change in phase or frequency input to output
- Vin as measured by ARB = 8.93

Input Output Response 5KHz to 8Ω Load

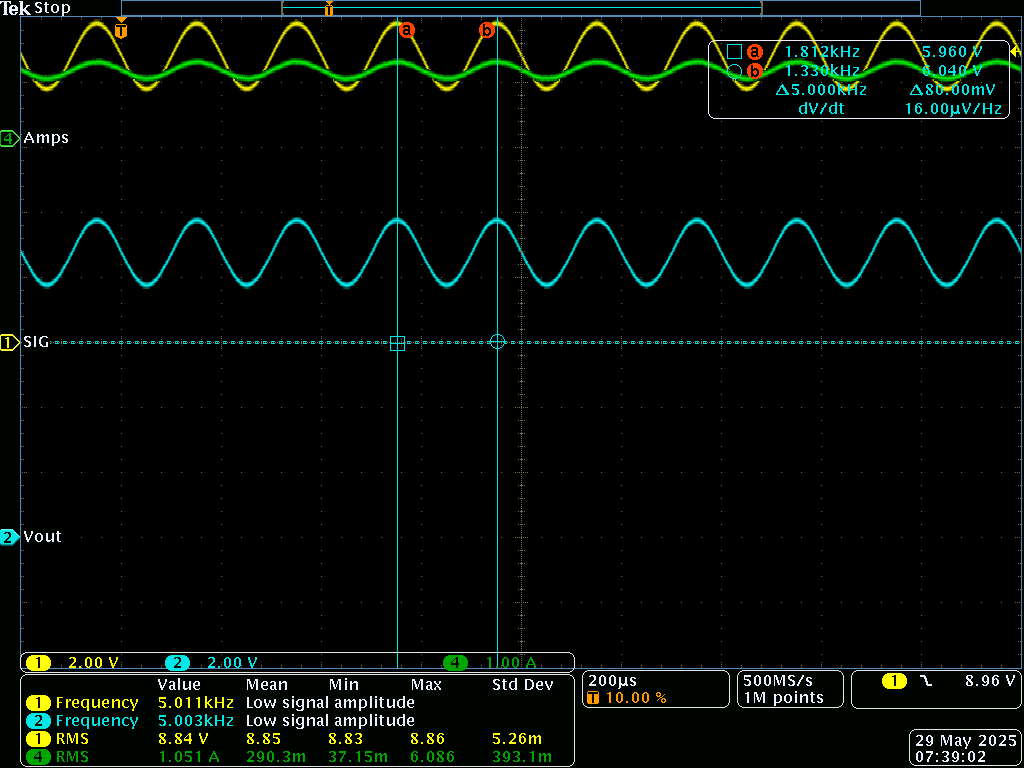
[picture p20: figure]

- No measurable change in phase or frequency input to output
- Vin as measured by ARB = 8.92Vrms
- Iout as measured by ARB = 1.061Irms
- Power To Load = 9.29W

## 4.4 Constant Current Mode Enable and Disable

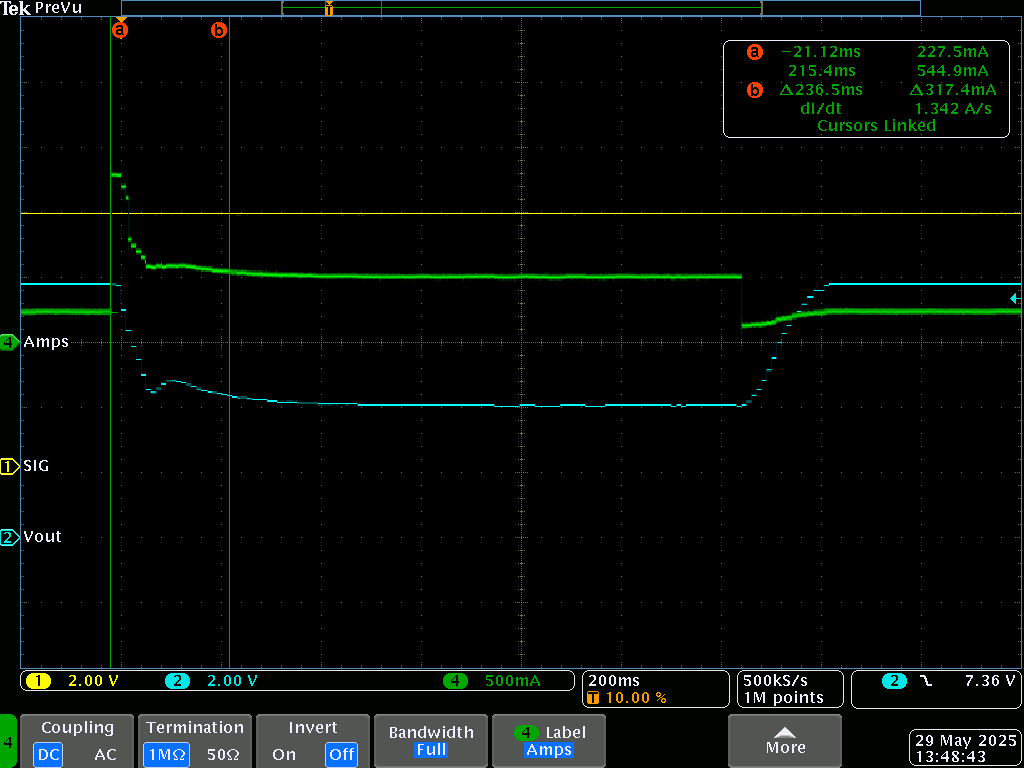
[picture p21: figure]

- CC Mode Limit set to 500mA
- Vin 8V
- Vout adjusted based on CC PID to match limit set point of 500mA
- Enable:
  - From a running load of 250mA a fault load of 1A is applied
  - CC mode activates in 236ms (to 95%)
- Disable:
  - From 500mA CC the fault load is reduced to 250mA
  - CC mode disable (150ms)

## 4.5 THERMAL PERFORMANCE

SETUP

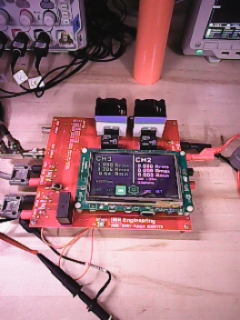
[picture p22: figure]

- Connected to 8Ω 100W resistor load not shown

THERMAL IMAGE CHANNEL 1

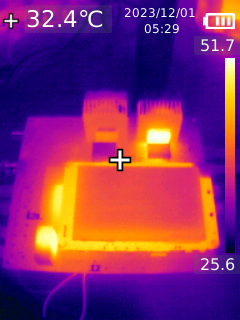
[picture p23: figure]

- On Time = 20min
- Output Current = 1.061Arms
- Output Voltage = 8.92Vrms
- PCB PLATED TO 1Oz
- Thermal camera not calibrated, temperature information is incorrect (not nearly that hot), but the image is useful in that you can see heat not being transferred to the heat sink – nothing here was hot to touch.

# 5. ACKNOWLEDGEMENT

FAMILY:

To the keeper of me, my beloved wife, I share everything with you. You are my strength in weakness, clarity in uncertainty and applause in victory. I accomplish nothing without your support, nor is anything of worth unless I can share it with you. I love you.

To my daughter Christina, my first born, we have matured and grown together. You are wonderful in spirit, a lover of children, and you put your heart into everything you do. Love is what you do. You are exceptional in so many ways; add to your gifts temperament and discernment and the world is yours.

To my daughter Faith, the Humanitarian, it is clear that you belong to the goodness of this world. You must remember that true greatness is only realized through service and that there are many ways to serve. Therein will be your pursuit – run to catch it. I hope I have shown you how to run.

To my daughter Trinity, the scientist, there is a clarity in the way you speak and think, in your questions and answers. You are to add to the scientific collective. Of the three, you are most like me. Don’t be afraid, nor ashamed of whom you are; accept it, and work hard to be.

To God Almighty, it is you that have made me, and not me myself – thank you for the many blessings, may I be a better servant and steward.

FRIEND:

Special thanks to my friend Walter Varda an absolute Rock Star of analog engineering and an even better person. His input in the earlier stages of the amplifier design process was most helpful to this project. Thank you Walter, you are one of the most generous people I have ever met in my life.

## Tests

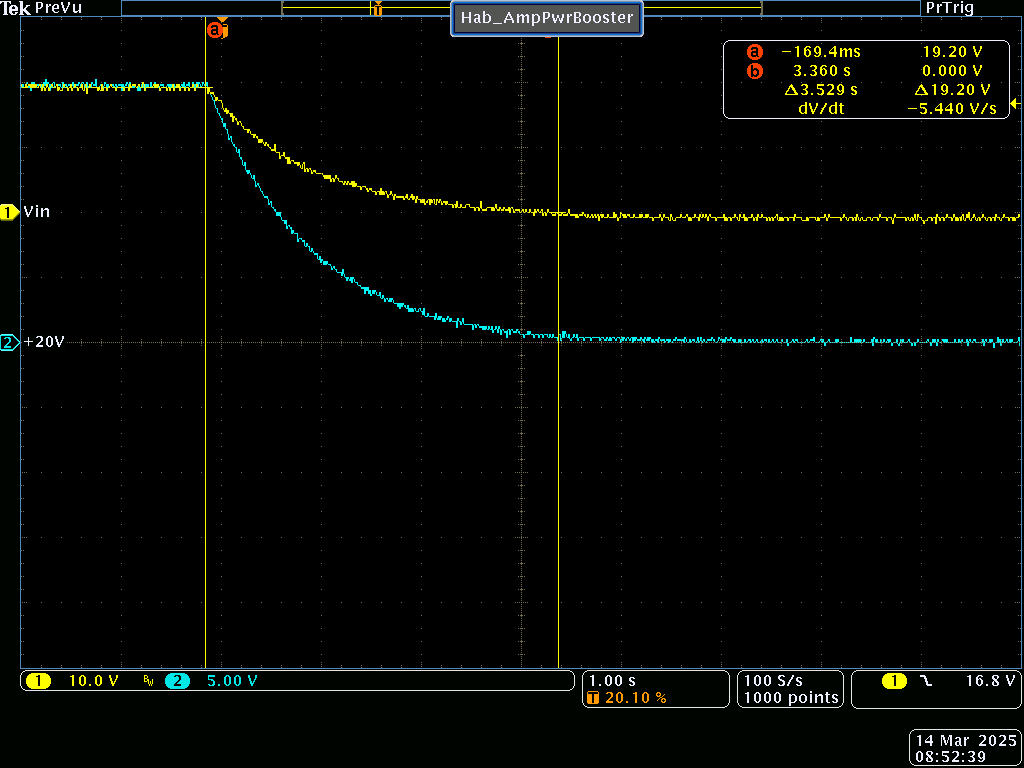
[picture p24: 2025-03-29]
TestResults/Pos_20V_Inrush_And_Discharge/Dischage.png

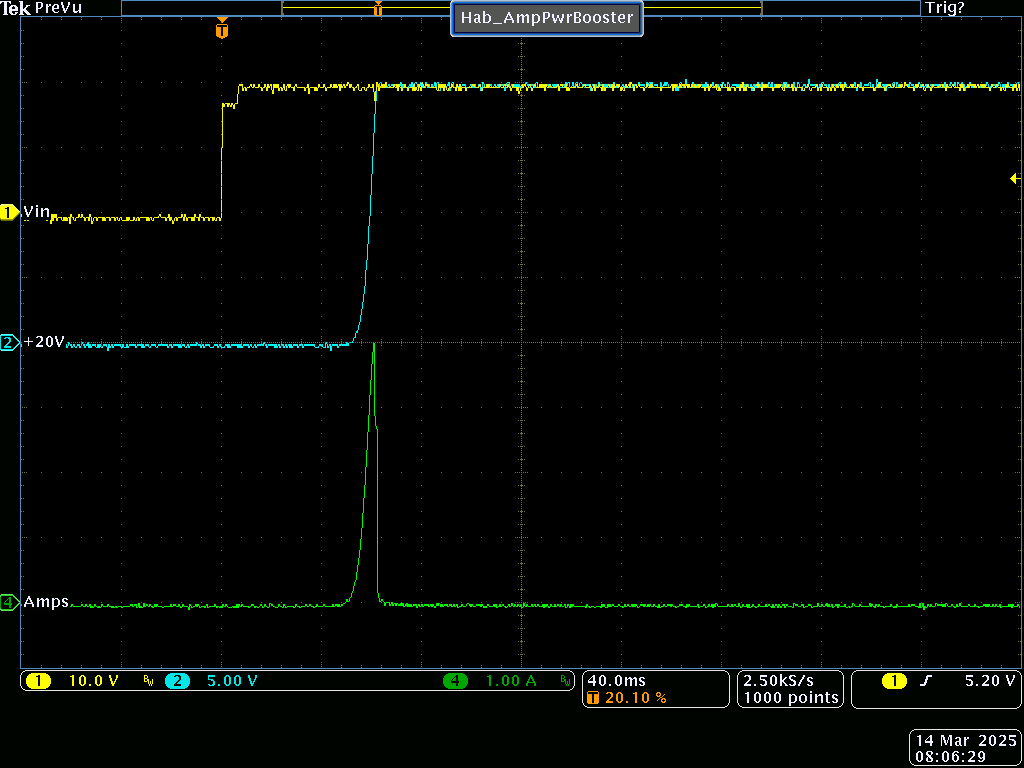
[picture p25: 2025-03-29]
TestResults/Pos_20V_Inrush_And_Discharge/Pos_20V_Inrush.png

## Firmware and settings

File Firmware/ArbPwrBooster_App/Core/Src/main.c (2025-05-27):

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
/* Includes ------------------------------------------------------------------*/
#include "main.h"
#include "cmsis_os.h"
#include "fatfs.h"
#include "libjpeg.h"
#include "app_touchgfx.h"

/* USER CODE BEGIN Includes */
#include "Main_Support.h"
#include "ADC_Support.h"
#include "Debug_Port.h"
/* USER CODE END Includes */

/* USER CODE BEGIN PD */

#define REFRESH_COUNT        1835

#define SDRAM_TIMEOUT                            ((uint32_t)0xFFFF)
#define SDRAM_MODEREG_BURST_LENGTH_1             ((uint16_t)0x0000)
#define SDRAM_MODEREG_BURST_LENGTH_2             ((uint16_t)0x0001)
#define SDRAM_MODEREG_BURST_LENGTH_4             ((uint16_t)0x0002)
#define SDRAM_MODEREG_BURST_LENGTH_8             ((uint16_t)0x0004)
#define SDRAM_MODEREG_BURST_TYPE_SEQUENTIAL      ((uint16_t)0x0000)
#define SDRAM_MODEREG_BURST_TYPE_INTERLEAVED     ((uint16_t)0x0008)
#define SDRAM_MODEREG_CAS_LATENCY_2              ((uint16_t)0x0020)
#define SDRAM_MODEREG_CAS_LATENCY_3              ((uint16_t)0x0030)
#define SDRAM_MODEREG_OPERATING_MODE_STANDARD    ((uint16_t)0x0000)
#define SDRAM_MODEREG_WRITEBURST_MODE_PROGRAMMED ((uint16_t)0x0000)
#define SDRAM_MODEREG_WRITEBURST_MODE_SINGLE     ((uint16_t)0x0200)

#define FLASH_READ_JEDEC_ID				0x9F
#define FLASH_FAST_READ_QUAD_IO		 	0xEB
#define FLASH_REVC03_MANUFACTURER_ID	0xEF
#define FLASH_N25Q128A_DUMMY_CYCLES		0x0A
#define FLASH_W25Q128J_DUMMY_CYCLES		0x06

/* USER CODE END PD */

ADC_HandleTypeDef hadc1;
ADC_HandleTypeDef hadc3;
DMA_HandleTypeDef hdma_adc1;
DMA_HandleTypeDef hdma_adc3;

CRC_HandleTypeDef hcrc;

DMA2D_HandleTypeDef hdma2d;

I2C_HandleTypeDef hi2c1;
I2C_HandleTypeDef hi2c3;

LTDC_HandleTypeDef hltdc;

QSPI_HandleTypeDef hqspi;

SD_HandleTypeDef hsd1;
DMA_HandleTypeDef hdma_sdmmc1_rx;
DMA_HandleTypeDef hdma_sdmmc1_tx;

UART_HandleTypeDef huart6;
DMA_HandleTypeDef hdma_usart6_tx;

SDRAM_HandleTypeDef hsdram1;

/* Definitions for defaultTask */
osThreadId_t defaultTaskHandle;
const osThreadAttr_t defaultTask_attributes = {
  .name = "defaultTask",
  .stack_size = 128 * 4,
  .priority = (osPriority_t) osPriorityNormal,
};
/* Definitions for TouchGFXTask */
osThreadId_t TouchGFXTaskHandle;
const osThreadAttr_t TouchGFXTask_attributes = {
  .name = "TouchGFXTask",
  .stack_size = 4096 * 4,
  .priority = (osPriority_t) osPriorityNormal,
};
/* Definitions for videoTask */
osThreadId_t videoTaskHandle;
const osThreadAttr_t videoTask_attributes = {
  .name = "videoTask",
  .stack_size = 1000 * 4,
  .priority = (osPriority_t) osPriorityLow,
};
/* Definitions for TaskMainUpdate */
osThreadId_t TaskMainUpdateHandle;
const osThreadAttr_t TaskMainUpdate_attributes = {
  .name = "TaskMainUpdate",
  .stack_size = 512 * 4,
  .priority = (osPriority_t) osPriorityLow,
};
/* Definitions for TaskDebugConsol */
osThreadId_t TaskDebugConsolHandle;
const osThreadAttr_t TaskDebugConsol_attributes = {
  .name = "TaskDebugConsol",
  .stack_size = 512 * 4,
  .priority = (osPriority_t) osPriorityLow,
};
/* Definitions for TaskMonitor */
osThreadId_t TaskMonitorHandle;
const osThreadAttr_t TaskMonitor_attributes = {
  .name = "TaskMonitor",
  .stack_size = 512 * 4,
  .priority = (osPriority_t) osPriorityLow,
};
/* Definitions for DisplayUpdateSemaphore */
osSemaphoreId_t DisplayUpdateSemaphoreHandle;
const osSemaphoreAttr_t DisplayUpdateSemaphore_attributes = {
  .name = "DisplayUpdateSemaphore"
};
/* USER CODE BEGIN PV */
static FMC_SDRAM_CommandTypeDef Command;
/* USER CODE END PV */

void SystemClock_Config(void);
static void MPU_Config(void);
static void MX_GPIO_Init(void);
static void MX_DMA_Init(void);
static void MX_CRC_Init(void);
static void MX_DMA2D_Init(void);
static void MX_FMC_Init(void);
static void MX_I2C3_Init(void);
static void MX_LTDC_Init(void);
static void MX_QUADSPI_Init(void);
static void MX_ADC1_Init(void);
static void MX_ADC3_Init(void);
static void MX_I2C1_Init(void);
static void MX_USART6_UART_Init(void);
static void MX_SDMMC1_SD_Init(void);
void StartDefaultTask(void *argument);
extern void TouchGFX_Task(void *argument);
extern void videoTaskFunc(void *argument);
void mainUpdateTask(void *argument);
void debugConsoleTask(void *argument);
void monitorTask(void *argument);

/* USER CODE BEGIN PFP */
void GetManufacturerId (uint8_t *manufacturer_id);
void EnableMemoryMappedMode(uint8_t manufacturer_id);  

/* USER CODE END PFP */

/**
  * @brief  The application entry point.
  * @retval int
  */
int main(void)
{

  /* MPU Configuration--------------------------------------------------------*/
  MPU_Config();

  /* Enable the CPU Cache */

  /* Enable I-Cache---------------------------------------------------------*/
  SCB_EnableICache();

  /* Enable D-Cache---------------------------------------------------------*/
  SCB_EnableDCache();

  /* MCU Configuration--------------------------------------------------------*/

  /* Reset of all peripherals, Initializes the Flash interface and the Systick. */
  HAL_Init();

  /* Configure the system clock */
  SystemClock_Config();

  /* Initialize all configured peripherals */
  MX_GPIO_Init();
  MX_DMA_Init();
  MX_CRC_Init();
  MX_DMA2D_Init();
  MX_FMC_Init();
  MX_I2C3_Init();
  MX_LTDC_Init();
  MX_QUADSPI_Init();
  MX_LIBJPEG_Init();
  MX_ADC1_Init();
  MX_ADC3_Init();
  MX_I2C1_Init();
  MX_USART6_UART_Init();
  MX_SDMMC1_SD_Init();
  MX_FATFS_Init();
  MX_TouchGFX_Init();
  /* Call PreOsInit function */
  MX_TouchGFX_PreOSInit();
  /* USER CODE BEGIN 2 */
  Init_ArbPwrBoosterClass();
  Init_ArbPwrBoosterHardware();
  /* USER CODE END 2 */

  /* Init scheduler */
  osKernelInitialize();

  /* USER CODE BEGIN RTOS_MUTEX */
  /* add mutexes, ... */
  /* USER CODE END RTOS_MUTEX */

  /* Create the semaphores(s) */
  /* creation of DisplayUpdateSemaphore */
  DisplayUpdateSemaphoreHandle = osSemaphoreNew(1, 1, &DisplayUpdateSemaphore_attributes);

  /* USER CODE BEGIN RTOS_SEMAPHORES */
  /* add semaphores, ... */
  /* USER CODE END RTOS_SEMAPHORES */

  /* USER CODE BEGIN RTOS_TIMERS */
  /* start timers, add new ones, ... */
  /* USER CODE END RTOS_TIMERS */

  /* USER CODE BEGIN RTOS_QUEUES */
  /* add queues, ... */
  /* USER CODE END RTOS_QUEUES */

  /* Create the thread(s) */
  /* creation of defaultTask */
  defaultTaskHandle = osThreadNew(StartDefaultTask, NULL, &defaultTask_attributes);

  /* creation of TouchGFXTask */
  TouchGFXTaskHandle = osThreadNew(TouchGFX_Task, NULL, &TouchGFXTask_attributes);

  /* creation of videoTask */
  videoTaskHandle = osThreadNew(videoTaskFunc, NULL, &videoTask_attributes);

  /* creation of TaskMainUpdate */
  TaskMainUpdateHandle = osThreadNew(mainUpdateTask, NULL, &TaskMainUpdate_attributes);

  /* creation of TaskDebugConsol */
  TaskDebugConsolHandle = osThreadNew(debugConsoleTask, NULL, &TaskDebugConsol_attributes);

  /* creation of TaskMonitor */
  TaskMonitorHandle = osThreadNew(monitorTask, NULL, &TaskMonitor_attributes);

  /* USER CODE BEGIN RTOS_THREADS */
  /* add threads, ... */
  /* USER CODE END RTOS_THREADS */

  /* USER CODE BEGIN RTOS_EVENTS */
  /* add events, ... */
  /* USER CODE END RTOS_EVENTS */

  /* Start scheduler */
  osKernelStart();

  /* We should never get here as control is now taken by the scheduler */

  /* Infinite loop */
  /* USER CODE BEGIN WHILE */
  while (1)
  {
    /* USER CODE END WHILE */

    /* USER CODE BEGIN 3 */
  }
  /* USER CODE END 3 */
}

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
/* USER CODE BEGIN 4 */

// Read manufacturer ID of external QSPI flash
void GetManufacturerId (uint8_t *manufacturer_id)
{
  QSPI_CommandTypeDef s_command_id;

  /* Initialize the read flag status register command */
  s_command_id.InstructionMode   = QSPI_INSTRUCTION_1_LINE;
  s_command_id.Instruction       = FLASH_READ_JEDEC_ID;
  s_command_id.AddressMode       = QSPI_ADDRESS_NONE;
  s_command_id.AlternateByteMode = QSPI_ALTERNATE_BYTES_NONE;
  s_command_id.DataMode          = QSPI_DATA_1_LINE;
  s_command_id.DummyCycles       = 0;
  s_command_id.NbData            = 1;
  s_command_id.DdrMode           = QSPI_DDR_MODE_DISABLE;
  s_command_id.DdrHoldHalfCycle  = QSPI_DDR_HHC_ANALOG_DELAY;
  s_command_id.SIOOMode          = QSPI_SIOO_INST_EVERY_CMD;

  /* Configure the command */
  if (HAL_QSPI_Command(&hqspi, &s_command_id, HAL_QPSI_TIMEOUT_DEFAULT_VALUE) != HAL_OK)
  {
	  Error_Handler();
  }

  /* Reception of the data */
  if (HAL_QSPI_Receive(&hqspi, manufacturer_id, HAL_QPSI_TIMEOUT_DEFAULT_VALUE) != HAL_OK)
  {
	  Error_Handler();
  }
}

// Enable memory mapped mode for external QSPI flash
void EnableMemoryMappedMode(uint8_t manufacturer_id)  
{
  QSPI_CommandTypeDef      s_command;
  QSPI_MemoryMappedTypeDef s_mem_mapped_cfg;

  /* Configure the command for the read instruction */
  s_command.InstructionMode   = QSPI_INSTRUCTION_1_LINE;
  s_command.Instruction       = FLASH_FAST_READ_QUAD_IO;
  s_command.AddressMode       = QSPI_ADDRESS_4_LINES;
  s_command.AddressSize       = QSPI_ADDRESS_24_BITS;
  s_command.AlternateByteMode = QSPI_ALTERNATE_BYTES_NONE;
  s_command.DataMode          = QSPI_DATA_4_LINES;
  
  // Set dummy cycles according to manufacturer ID
  s_command.DummyCycles       = manufacturer_id == FLASH_REVC03_MANUFACTURER_ID ? FLASH_W25Q128J_DUMMY_CYCLES : FLASH_N25Q128A_DUMMY_CYCLES;

  s_command.DdrMode           = QSPI_DDR_MODE_DISABLE;
  s_command.DdrHoldHalfCycle  = QSPI_DDR_HHC_ANALOG_DELAY;
  s_command.SIOOMode          = QSPI_SIOO_INST_EVERY_CMD;
  
  /* Configure the memory mapped mode */
  s_mem_mapped_cfg.TimeOutActivation = QSPI_TIMEOUT_COUNTER_DISABLE;
  s_mem_mapped_cfg.TimeOutPeriod     = 0;
  
  if (HAL_QSPI_MemoryMapped(&hqspi, &s_command, &s_mem_mapped_cfg) != HAL_OK)
  {
    Error_Handler();
  }
}

/* USER CODE END 4 */

/* USER CODE BEGIN Header_StartDefaultTask */
/**
  * @brief  Function implementing the defaultTask thread.
  * @param  argument: Not used
  * @retval None
  */
/* USER CODE END Header_StartDefaultTask */
void StartDefaultTask(void *argument)
{
  /* USER CODE BEGIN 5 */

  /* Infinite loop */
  for(;;)
  {

    osDelay(5000);
  }
  /* USER CODE END 5 */
}

/* USER CODE BEGIN Header_mainUpdateTask */
/**
* @brief Function implementing the TaskMainUpdate thread.
* @param argument: Not used
* @retval None
*/
/* USER CODE END Header_mainUpdateTask */
void mainUpdateTask(void *argument)
{
  /* USER CODE BEGIN mainUpdateTask */
  mainUpdateTaskInit();
  /* Infinite loop */
  for(;;)
  {
      mainUpdateTaskActions();
  }
  /* USER CODE END mainUpdateTask */
}

/* USER CODE BEGIN Header_debugConsoleTask */
/**
* @brief Function implementing the TaskDebugConsol thread.
* @param argument: Not used
* @retval None
*/
/* USER CODE END Header_debugConsoleTask */
void debugConsoleTask(void *argument)
{
  /* USER CODE BEGIN debugConsoleTask */
  debugConsoleTaskInit();
  /* Infinite loop */
  for(;;)
  {
      debugConsoleTaskActions();
  }
  /* USER CODE END debugConsoleTask */
}

/* USER CODE BEGIN Header_monitorTask */
/**
* @brief Function implementing the TaskMonitor thread.
* @param argument: Not used
* @retval None
*/
/* USER CODE END Header_monitorTask */
void monitorTask(void *argument)
{
  /* USER CODE BEGIN monitorTask */
  monitorTaskInit();
  /* Infinite loop */
  for(;;)
  {
    monitorTaskActions();
  }
  /* USER CODE END monitorTask */
}

 /* MPU Configuration */

void MPU_Config(void)
{
  MPU_Region_InitTypeDef MPU_InitStruct = {0};

  /* Disables the MPU */
  HAL_MPU_Disable();

  /** Initializes and configures the Region and the memory to be protected
  */
  MPU_InitStruct.Enable = MPU_REGION_ENABLE;
  MPU_InitStruct.Number = MPU_REGION_NUMBER0;
  MPU_InitStruct.BaseAddress = 0x90000000;
  MPU_InitStruct.Size = MPU_REGION_SIZE_256MB;
  MPU_InitStruct.SubRegionDisable = 0x0;
  MPU_InitStruct.TypeExtField = MPU_TEX_LEVEL0;
  MPU_InitStruct.AccessPermission = MPU_REGION_FULL_ACCESS;
  MPU_InitStruct.DisableExec = MPU_INSTRUCTION_ACCESS_ENABLE;
  MPU_InitStruct.IsShareable = MPU_ACCESS_NOT_SHAREABLE;
  MPU_InitStruct.IsCacheable = MPU_ACCESS_NOT_CACHEABLE;
  MPU_InitStruct.IsBufferable = MPU_ACCESS_NOT_BUFFERABLE;

  HAL_MPU_ConfigRegion(&MPU_InitStruct);

  /** Initializes and configures the Region and the memory to be protected
  */
  MPU_InitStruct.Number = MPU_REGION_NUMBER1;
  MPU_InitStruct.Size = MPU_REGION_SIZE_16MB;
  MPU_InitStruct.IsCacheable = MPU_ACCESS_CACHEABLE;

  HAL_MPU_ConfigRegion(&MPU_InitStruct);
  /* Enables the MPU */
  HAL_MPU_Enable(MPU_PRIVILEGED_DEFAULT);

}

/**
  * @brief  Period elapsed callback in non blocking mode
  * @note   This function is called  when TIM6 interrupt took place, inside
  * HAL_TIM_IRQHandler(). It makes a direct call to HAL_IncTick() to increment
  * a global variable "uwTick" used as application time base.
  * @param  htim : TIM handle
  * @retval None
  */
void HAL_TIM_PeriodElapsedCallback(TIM_HandleTypeDef *htim)
{
  if (htim->Instance == TIM6) {
    HAL_IncTick();
  }
}

/**
  * @brief  This function is executed in case of error occurrence.
  * @retval None
  */
void Error_Handler(void)
{
  /* USER CODE BEGIN Error_Handler_Debug */
  /* User can add his own implementation to report the HAL error return state */

  /* USER CODE END Error_Handler_Debug */
}

#ifdef  USE_FULL_ASSERT
/**
  * @brief  Reports the name of the source file and the source line number
  *         where the assert_param error has occurred.
  * @param  file: pointer to the source file name
  * @param  line: assert_param error line source number
  * @retval None
  */
void assert_failed(uint8_t *file, uint32_t line)
{
  /* USER CODE BEGIN 6 */
  /* User can add his own implementation to report the file name and line number,
     tex: printf("Wrong parameters value: file %s on line %d\r\n", file, line) */
  /* USER CODE END 6 */
}
#endif /* USE_FULL_ASSERT */

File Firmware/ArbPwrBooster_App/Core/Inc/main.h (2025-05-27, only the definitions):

#define EN_VO_2_Pin GPIO_PIN_4
#define EN_VO_2_GPIO_Port GPIOB
#define R_SHDN_1_Pin GPIO_PIN_15
#define R_SHDN_1_GPIO_Port GPIOA
#define EN_50_Z_2_Pin GPIO_PIN_3
#define EN_50_Z_2_GPIO_Port GPIOI
#define EN_VO_1_Pin GPIO_PIN_2
#define EN_VO_1_GPIO_Port GPIOI
#define USD_DETECT_Pin GPIO_PIN_13
#define USD_DETECT_GPIO_Port GPIOC
#define LCD_BL_CTRL_Pin GPIO_PIN_3
#define LCD_BL_CTRL_GPIO_Port GPIOK
#define EN_FAN_1_Pin GPIO_PIN_1
#define EN_FAN_1_GPIO_Port GPIOI
#define LCD_DISP_Pin GPIO_PIN_12
#define LCD_DISP_GPIO_Port GPIOI
#define R_SHDN_2_Pin GPIO_PIN_0
#define R_SHDN_2_GPIO_Port GPIOI
#define EN_CH_1_Pin GPIO_PIN_8
#define EN_CH_1_GPIO_Port GPIOA
#define EN_FAN_2_Pin GPIO_PIN_7
#define EN_FAN_2_GPIO_Port GPIOG
#define MAIN_PWR_EN_Pin GPIO_PIN_6
#define MAIN_PWR_EN_GPIO_Port GPIOG
#define IO_MON_2_Pin GPIO_PIN_10
#define IO_MON_2_GPIO_Port GPIOF
#define POS_20V_MON_Pin GPIO_PIN_9
#define POS_20V_MON_GPIO_Port GPIOF
#define NEG_20V_MON_Pin GPIO_PIN_8
#define NEG_20V_MON_GPIO_Port GPIOF
#define EN_CH_2_Pin GPIO_PIN_6
#define EN_CH_2_GPIO_Port GPIOH
#define ADC3_CRATE_Pin GPIO_PIN_14
#define ADC3_CRATE_GPIO_Port GPIOB
#define EN_50_Z_1_Pin GPIO_PIN_15
#define EN_50_Z_1_GPIO_Port GPIOB

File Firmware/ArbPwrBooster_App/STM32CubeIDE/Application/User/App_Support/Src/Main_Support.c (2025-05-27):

/** ****************************************************************************************************
 * @file 			Main_Support.c
 * @brief			Functions that support the Arbitrary Power Booster Hardware
 * ****************************************************************************************************
 * @author original Hab Collector (habco)\n
 *
 * @version         See Main_Support.h: FW_MAJOR_REV, FW_MINOR_REV, FW_TEST_REV
 *
 * @param Development_Environment \n
 * Hardware:        <STM32F764G-DISCO> \n
 * IDE:             STMCubeIDE VER 1.17.0 \n
 * Compiler:        GCC \n
 * Editor Settings: 1 Tab = 4 Spaces, Recommended Courier New 11
 *
 * @note            The associated header file provides MACRO functions for IO control
 *
 *                  This is an embedded application
 *                  It will be necessary to consult the reference documents to fully understand the code
 *                  It is suggested that the documents be reviewed in the order shown.
 *                    Schematic: IMR-005-SCH
 *                    STM32F746G_DISCO
 *                    IMR
 *
 * @copyright       IMR Engineering, LLC
 ********************************************************************************************************/
#include "Main_Support.h"
#include "ADC_Support.h"
#include "IO_Support.h"
#include "UART_Support.h"
#include "Debug_Port.h"
#include "Terminal_Emulator_Support.h"
#include "MCP45HVX1_Driver.h"
#include "cmsis_os2.h"
#include "ff.h"
#include <String.h>
#include <stdlib.h>
#include <stdio.h>

extern osSemaphoreId_t DisplayUpdateSemaphoreHandle;
extern FATFS SDFatFS;
extern char SDPath[4];

// GLOBALS
Type_ArbPwrBoosterStatus ArbPwrBooster;



/********************************************************************************************************
* @brief Init of the Arbitrary Power Booster hardware peripherals and drivers for use in POR state
*
* @author original: Hab Collector \n
*
* STEP 1: Init hardware peripherals
* STEP 2: Init drivers
********************************************************************************************************/
void Init_ArbPwrBoosterHardware(void)
{
    // STEP 1: Init hardware peripherals
    Init_GPIO_Hardware();
    Init_ADC_Hardware();
    Init_UART_Hardware();

    // STEP 2: Init drivers
    Init_MCP45HVX1();

} // END OF Init_ArbPwrBoosterHardware



/********************************************************************************************************
* @brief Init of the Arbitrary Power Booster class - set member values to defaults for POR operation
*
* @author original: Hab Collector \n
*
* STEP 1: Set members to default POR value
********************************************************************************************************/
void Init_ArbPwrBoosterClass(void)
{
    // STEP 1: Set members to default POR value
    ArbPwrBooster.Ready = false;
    ArbPwrBooster.ActiveChannel = CHANNEL_1;
    ArbPwrBooster.Screen = SPLASH_SCREEN;
    // Channel 1 Init
    ArbPwrBooster.CH1.InputImpedance = ONE_MEG_OHM;
    ArbPwrBooster.CH1.OutputSwitch = OFF;
    ArbPwrBooster.CH1.Limit.Enable = true;
    ArbPwrBooster.CH1.Limit.Current = 0.300;
    ArbPwrBooster.CH1.Measure.ResetCurrentMinMax = true;
    ArbPwrBooster.CH1.Measure.MaxCurrent = 0;
    ArbPwrBooster.CH1.Measure.MinCurrent = 0;
    ArbPwrBooster.CH1.Measure.RMS_CurrentFunction = update_RMS_Value;
    ArbPwrBooster.CH1.Measure.ZeroCurrentVoltage = CURRENT_MON_ZERO_OFFSET;
    ArbPwrBooster.CH1.Measure.ResetVoltageMinMax = true;
    ArbPwrBooster.CH1.Measure.MinVoltage = 0;
    ArbPwrBooster.CH1.Measure.MaxVoltage = 0;
    ArbPwrBooster.CH1.Measure.RMS_VoltageFunction = update_RMS_Value;
    ArbPwrBooster.CH1.Fan.Enable = false;
    // Channel 2 Init
    ArbPwrBooster.CH2.InputImpedance = ONE_MEG_OHM;
    ArbPwrBooster.CH2.OutputSwitch = OFF;
    ArbPwrBooster.CH2.Limit.Enable = true;
    ArbPwrBooster.CH2.Limit.Current = 1.250;
    ArbPwrBooster.CH2.Measure.ResetCurrentMinMax = true;
    ArbPwrBooster.CH2.Measure.MaxCurrent = 0;
    ArbPwrBooster.CH2.Measure.MinCurrent = 0;
    ArbPwrBooster.CH2.Measure.RMS_CurrentFunction = update_RMS_Value;
    ArbPwrBooster.CH2.Measure.ZeroCurrentVoltage = CURRENT_MON_ZERO_OFFSET;
    ArbPwrBooster.CH2.Measure.ResetVoltageMinMax = true;
    ArbPwrBooster.CH2.Measure.MinVoltage = 0;
    ArbPwrBooster.CH2.Measure.MaxVoltage = 0;
    ArbPwrBooster.CH2.Measure.RMS_VoltageFunction = update_RMS_Value;
    ArbPwrBooster.CH2.Fan.Enable = false;

} // END OF Init_ArbPwrBoosterClass



/********************************************************************************************************
* @brief Convert the a rational number in the form of A.xyz into its unique components of A, x, y, z
*   A = Integer
*   x = Tenths
*   y = Hundredths
*   z = Thousandths
* Example Rational number 3.1429 becomes A = 3, x = 1, y = 4, z = 3
*
* @author original: Hab Collector \n
*
* @note: Values are rounded up to the nearest thousandths
* @note: Integer, Tenths, Hundredths, Thousandths are returned by reference
* @note: Used in setting of current limit
*
* @param RationalNumber: Value to be converted
* @param Integer: Said place holder within a rational number
* @param Tenths: Said place holder within a rational number
* @param Hundredths: Said place holder within a rational number
* @param Thousandths: Said place holder within a rational number
*
* STEP 1: Locate the decimal by pointer
* STEP 2: Extract Integer Part
* STEP 3: Extract Tenths
* STEP 4: Extract Hundredths
* STEP 5: Extract Thousandths
********************************************************************************************************/
void digitsFromDouble(double RationalNumber, int8_t *Integer, uint8_t *Tenths, uint8_t *Hundredths, uint8_t *Thousandths)
{
    char ValueString[10] = {0};
    char ExtractedString[3] = {0};
    char *DecimalLocation;

    // STEP 1: Locate the decimal by pointer
    sprintf(ValueString, "%2.3f", RationalNumber);
    DecimalLocation = strstr(ValueString, ".");

    // STEP 2: Extract Integer Part
    uint8_t StringLength = strlen(ValueString);
    for (uint8_t Index = 0; Index < StringLength; Index++)
    {
        if (ValueString[Index] == '.')
            break;
        ExtractedString[Index] = ValueString[Index];
    }
    *Integer = atoi(ExtractedString);

    // STEP 3: Extract Tenths
    memset(ExtractedString, 0x00, sizeof(ExtractedString));
    char *ValueLocationTenths = DecimalLocation + 1;
    ExtractedString[0] = *ValueLocationTenths;
    *Tenths = atoi(ExtractedString);

    // STEP 4: Extract Hundredths
    char *ValueLocationHundredths = DecimalLocation + 2;
    ExtractedString[0] = *ValueLocationHundredths;
    *Hundredths = atoi(ExtractedString);

    // STEP 5: Extract Thousandths
    char *ValueLocationThousandths = DecimalLocation + 3;
    ExtractedString[0] = *ValueLocationThousandths;
    *Thousandths = atoi(ExtractedString);

} // END OF digitsFromDouble
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

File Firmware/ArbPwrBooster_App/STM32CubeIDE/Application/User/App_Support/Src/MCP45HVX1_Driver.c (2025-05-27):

/******************************************************************************************************
 * @file 			MCP45HVX1_Driver.c
 * @brief			Supports the I2C interface of Microchip MCP45HVX1 family of products
 * ****************************************************************************************************
 * @author original	Hab Collector (habco)\n
 *
 * @version       	See Main_Support.h: FIRMWARE_REV_MAJOR, FIRMWARE_REV_MINOR
 *
 * @param Development_Environment \n
 * Hardware:		<IC PN> \n
 * IDE:             STMCubeIDE VER 1.9.0 \n
 * Compiler:        GCC \n
 * Editor Settings: 1 Tab = 4 Spaces, Recommended Courier New 11
 *
 * @note            The associated header file provides MACRO functions for IO control
 *
 * 					This is an embedded application
 *		            It will be necessary to consult the reference documents to fully understand the code
 *                  It is suggested that the documents be reviewed in the order shown.
 *			          Schematic: <Schematic PN>
 *				      STM32F746G_DISCO
 *				      ACI Pittsburgh
 *
 * @copyright		Applied Concepts, Inc
 ******************************************************************************************************/

#include "MCP45HVX1_Driver.h"
#include "Terminal_Emulator_Support.h"


/********************************************************************************************************
* @brief Init of the MCP45HVX1 for use on the board.  Note there are two channels to be init.  Enable the
* device and set the output to max span on the POT
*
* @author original: Hab Collector \n
*
* STEP 1: Init Channel 1
* STEP 2: Init Channel 2
********************************************************************************************************/
void Init_MCP45HVX1(void)
{
    // STEP 1: Init Channel 1
    MCP45HVX1_ENABLE_CH1();
#ifdef USING_WIPER_I2C_LATCH
    MCP45HVX1_I2C_PASS_CH1();
#endif
    MCP45HVX1_WriteWiperVerify(&hi2c1, A1A0_EXTERNAL_ADDR_CH1, MCP45HVX1_POT_FULL_RESOLUTION);

    // STEP 2: Init Channel 2
    MCP45HVX1_ENABLE_CH2();
#ifdef USING_WIPER_I2C_LATCH
    MCP45HVX1_I2C_PASS_CH2();
#endif
    MCP45HVX1_WriteWiperVerify(&hi2c1, A1A0_EXTERNAL_ADDR_CH2, MCP45HVX1_POT_FULL_RESOLUTION);

} // END OF Init_MCP45HVX1



/********************************************************************************************************
* @brief Write the wiper value to the device.
*
* @author original: Hab Collector \n
*
* @note: Note the max pot value is defined by the USING_MCP45HV31 or USING_MCP45H531
*
* @param I2C_Handle: I2C Handle
* @param A1A0_ExternalAddress: The hardware set address of A1 and A0 of the chip
* @param Value: The wiper value - max value depends on chip in use - see notes
*
* @return True if I2C HAL transmitted OK
*
* STEP 1: Build the I2C Address
* STEP 2: Load the command and the pot wiper value to data
* STEP 3: Transmit the command
********************************************************************************************************/
bool MCP45HVX1_WriteWiperValue(I2C_HandleTypeDef *I2C_Handle, uint8_t A1A0_ExternalAddress, uint8_t Value)
{
    uint8_t I2C_Address;
    uint8_t CommandDataBuffer[2] = {0x00};

    // STEP 1: Build the I2C Address
    I2C_Address = MCP45HVX1_FIXED_ADDRESS | (A1A0_ExternalAddress << 1);

    // STEP 2: Load the command and the pot wiper value to data
    CommandDataBuffer[0] = ((MCP45HVX1_VOLATILE_WIPER_0_ADDR & 0x0F) << 4) | ((MCP45HVX1_WRITE_COMMAND & 0x03) << 2);
    CommandDataBuffer[1] = Value;

    // STEP 3: Transmit the command
    HAL_StatusTypeDef Status = HAL_I2C_Master_Transmit(I2C_Handle, I2C_Address, CommandDataBuffer, sizeof(CommandDataBuffer), HAL_MAX_DELAY);
    if (Status == HAL_OK)
        return(true);
    else
        return(false);

} // END OF MCP45HVX1_WriteWiperValue



/********************************************************************************************************
* @brief Read the wiper value from the device.  From the datasheet this would be referred to as a random
* read command since it consists of a write to set the command followed by a read
*
* @author original: Hab Collector \n
*
* @note: Note the max pot value is defined by the USING_MCP45HV31 or USING_MCP45H531
*
* @param I2C_Handle: I2C Handle
* @param A1A0_ExternalAddress: The hardware set address of A1 and A0 of the chip
* @param Value: The wiper value (returned by reference) - max value depends on chip in use - see notes
*
* @return True if I2C HAL transmitted / Read OK
*
* STEP 1: Build the I2C Address and command
* STEP 2: Transmit the command
* STEP 3: Read the value via I2C - note two bytes are read
********************************************************************************************************/
bool MCP45HVX1_ReadWiperValue(I2C_HandleTypeDef *I2C_Handle, uint8_t A1A0_ExternalAddress, uint8_t *Value)
{
    uint8_t I2C_Address;
    uint8_t Command = 0x00;

    // STEP 1: Build the I2C Address and command
    I2C_Address = MCP45HVX1_FIXED_ADDRESS | (A1A0_ExternalAddress << 1);
    Command = ((MCP45HVX1_VOLATILE_WIPER_0_ADDR & 0x0F) << 4) | ((MCP45HVX1_READ_COMMAND & 0x03) << 2);

    // STEP 2: Transmit the command
    if (HAL_I2C_Master_Transmit(I2C_Handle, I2C_Address, &Command, 1, HAL_MAX_DELAY) != HAL_OK)
        return(false);

    // STEP 3: Read the value via I2C - note two bytes are read
    uint8_t ReadBytes[2] = {0};
    HAL_StatusTypeDef Status = HAL_I2C_Master_Receive(I2C_Handle, I2C_Address, ReadBytes, 2, HAL_MAX_DELAY);
    *Value = ReadBytes[1];
    if (Status == HAL_OK)
        return(true);
    else
    {
#ifdef MCP45HVX1_USES_PRINTF
        printRed("ERROR: MCP45HVX1 Failed to read\r\n");
#endif
        return(false);
    }

} // END OF MCP45HVX1_ReadWiperValue
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

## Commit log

2025-02-07 Initial commit of project to repo
    [ArbPwrBoost_P1.SchDoc, ArbPwrBoost_P2.SchDoc, Arb_Power_Booster.PrjPcb]
2025-02-10 Added many addtions to SCH and PCB library. Added to schematic
    [ArbPwrBoost_P2.SchDoc, Arb_Power_Booster.PrjPcb]
2025-02-10 Changes to sch lib and created new sch lib without alias issue
    [ArbPwrBoost_P2.SchDoc]
2025-02-11 Additions and corrections to sch lib R2. Added page 3, completed more of page 2
    [ArbPwrBoost_P1.SchDoc, ArbPwrBoost_P2.SchDoc, ArbPwrBoost_P3.SchDoc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]
2025-02-13 Many additions and changes to schematics and libraries
    [ArbPwrBoost_P2.SchDoc, ArbPwrBoost_P3.SchDoc, ArbPwrBoost_P4.SchDoc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]
2025-02-15 Fine tuning CH1
    [ArbPwrBoost_P1.SchDoc, ArbPwrBoost_P2.SchDoc, ArbPwrBoost_P3.SchDoc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]
2025-02-17 Added CH2 to the design
    [ArbPwrBoost_P1.SchDoc, ArbPwrBoost_P2.SchDoc, ArbPwrBoost_P3.SchDoc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]
2025-02-18 Component placement done. Fixes to SCH and PCB lib. Added mounting holes
    [ArbPwrBoost_P2.SchDoc, ArbPwrBoost_P3.SchDoc, ArbPwrBoost_P4.SchDoc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]
2025-02-19 Moved display and tall relays to other side. Fine tune placement
2025-02-20 Much routing in place, but want to experiment with flipping the display
    [ArbPwrBoost_P5.SchDoc]
2025-02-20 Routing complete with all but 3 SSMC non-critical errors
    [ArbPwrBoost+20V.csv, ArbPwrBoost-20V.csv, ArbPwrBoost.csv]
2025-02-21 Change bleed resistor from 100K to 10K. Completed top silk REF DES
    [ArbPwrBoost_P2.SchDoc, Arb_Power_Booster.PrjPcb]
2025-02-25 Added protection SSR on input channels. Created output job
    [ArbPwrBoost.GBL, ArbPwrBoost.GBO, ArbPwrBoost.GBP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]
2025-02-25 Updated output job
    [ArbPwrBoost.GBL, ArbPwrBoost.GBO, ArbPwrBoost.GBP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]
2025-02-28 Added ToughGFX project completed Splash and Main Screen
    [ArbPwrBoost.GBL, ArbPwrBoost.GBO, ArbPwrBoost.GBP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]
2025-02-28 Added more to TouchGFX screens. Created Test Plan. Added notes to schematic
    [ArbPwrBoost_P2.SchDoc, BOM_PartType-Arb_Power_Booster.xlsx]
2025-03-02 Touch GFX way to increment set digits and refinement to variable names. Added LTSpice circuit to add back in Vbe offset of current booster.
    [ArbPwrBoost.GBL, ArbPwrBoost.GBO, ArbPwrBoost.GBP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]
2025-03-02 Created STM32 Project. Modified several text areas to wild cards within Config
2025-03-03 Created a REV1 zip for PCB Build. Modified .ioc file and for MAIN_PWR_EN. Clean up and notes added to project
    [BOM_PartType-Arb_Power_Booster.xlsx]
2025-03-05 Added ADC Support to project ADC1, ADC3 6 CHs total in DMA contineous conversion. Fixed alignment of MainScreen CH1 display Arms
    [ADC_Support.c, ADC_Support.h, IO_Support.c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]
2025-03-06 Added Hab_Types.h to project. Many additions and bug fixes to set screen. Commenting clen up
    [Main_Support.c]
2025-03-07 Changed all instance so ArbPwrBossterStatus to ArbPwrBooster. Removed magic numbers in code. Added min max reset
    [Main_Support.c, Screen_SplashView.cpp]
2025-03-08 Fixed System Temp measure. Added FIFO init and write functions. Added calculateSystem_3V3, calculateSystemTemp
    [ADC_Support.c, ADC_Support.h]
2025-03-10 ADC1 to 2 channels DMA one shot. ADC3 to 4 channels DMA contineous. Conversions time change. Working on RMS
2025-03-11 Bug fix of FIFO sum in writeTo_FIFO_Buffer(). Added header commenting. Added error handler and some use cases.
    [ADC_Support.c, ADC_Support.h, Main_Support.c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]
2025-03-12 Added RMS current measure
2025-03-29 Many changes: Changes and additions to simulation. To Firmware Added UART for debug console. Added Debug Console task and support functions
2025-03-29 Added header comments. Clean up. name change of setDigitalPotAttenuation to writeDigitalPotAttenuation and bug fix - ready to call the actual pot set
    [Debug_Port.c, Main_Support.c, UART_Support.c]
2025-03-30 Added MCP45HVX1 Driver functions. Added repeat command to console
2025-03-31 Changed ADC3 and ADC1 Conversion Rate IO to PB14 and PI1 respectively. Added Voltage monitor on ADC3 IN4 and IN5 - ADC3 now has 6 ADCs
2025-04-01 Enhanced the splash screen intro - made it smoother by delaying the start of ADC 1 and ADC 3 converstions
2025-04-04 Created recovery point for schematic and pcb
    [ArbPwrBoost.GBL, ArbPwrBoost.GBO, ArbPwrBoost.GBP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]
2025-04-08 Fixed all issues in schematic and PCB. Does not have booster drive interface corrrection. Does not have ABS Value circuit.
    [ArbPwrBoost_P2.SchDoc, ArbPwrBoost_P3.SchDoc, ArbPwrBoost_P4.SchDoc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]
2025-04-09 Added absolute value circuit and placement and route
    [ArbPwrBoost_P44.SchDoc, ArbPwrBoost_P5.SchDoc]
2025-04-14 Changes to power booster added to schematic and PCB
    [ArbPwrBoost_P1.SchDoc, ArbPwrBoost_P2.SchDoc, ArbPwrBoost_P3.SchDoc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]
2025-04-14 Removed gaps in ref des on schematic and PCB - this is not a renumber
    [ArbPwrBoost_P3.SchDoc, ArbPwrBoost_P5.SchDoc, ArbPwrBoost_P6.SchDoc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]
2025-04-15 Created output job and zip file to order at REV 2
    [ArbPwrBoost.GBL, ArbPwrBoost.GBO, ArbPwrBoost.GBP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]
2025-04-19 Changed comments and var references of supply voltage being 20V to just VS - As the supply voltage will no longer be 20V this would have been confusing.
    [ADC_Support.c, ADC_Support.h]
2025-04-19 No display of current set point on main screen if current limit not enabled. Some header clean up. Rename of function update_main_screen to updateScreenMainOnEntry
2025-04-19 Changed the way reset min max works. Changed Config display to show+/-VS and not +/-20V. Changed Main screen to center config flex button
    [ADC_Support.c, Main_Support.c]
2025-04-26 Added input voltage RMS for CH1 and CH2
2025-04-29 Modified ADC3 changed sample times. Working Current Sense - but not accurate
2025-04-29 Added Vrms CH1 and 2 to main display. Bug fix for negative values on min max in main display
    [ADC_Support.c]
2025-04-30 Made a single RMS calculate function - replaced 4 others. Bug fix not being able to do all 4 RMS calculations - reduced the sampling rate from 21.496KHz to 15.663KHz to do this
    [ADC_Support.c, ADC_Support.h, Main_Support.c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]
2025-05-02 Moved RMS functions to dedicated file. Added PID - not tested and commented out. Added CC icon to main display - needs to be incorporated
2025-05-06 Added heat sink and fan to lib. Bug fix in ABS circuit
    [ArbPwrBoost_P1.SchDoc, ArbPwrBoost_P2.SchDoc, ArbPwrBoost_P3.SchDoc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]
2025-05-07 Removed current booster and relay jumper circuits from SCH and PCB
    [ArbPwrBoost_P2.SchDoc, ArbPwrBoost_P3.SchDoc, ArbPwrBoost_P4.SchDoc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]
2025-05-07 Made schematic and PCB ready to add changes
    [ArbPwrBoost_P3.SchDoc, ArbPwrBoost_P6.SchDoc]
2025-05-07 Schematic additions ready for REF DES annotation
    [ArbPwrBoost_P3.SchDoc, ArbPwrBoost_P4.SchDoc, ArbPwrBoost_P5.SchDoc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]
2025-05-08 Placement and routing in place - working on cleaning up silk screen
    [ArbPwrBoost_P4.SchDoc, ArbPwrBoost_P5.SchDoc, ArbPwrBoost_P7.SchDoc]
2025-05-09 Added mechanical hardware. Moved banana connectors more off board. DRC OK
    [ArbPwrBoost_P5.SchDoc]
2025-05-11 Replaced D6 from 1A to 2A diode. Added pi filter on output of power supply. Added 2x single pole filter on the use of 1.65V reference. Minor changes to layout and misc
    [ArbPwrBoost.GBL, ArbPwrBoost.GBO, ArbPwrBoost.GBP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]
2025-05-13 REV 3 Files to PCB FAB
    [BOM_PartType-Arb_Power_Booster.xlsx]
2025-05-16 Hardware modified REV 3 for board outline and cut-outs. Firmware modified the PID struct and how it is called. Added magenta color print. Added Status command to debug. Processor option to printf err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
    [ArbPwrBoost.GBL, ArbPwrBoost.GBO, ArbPwrBoost.GBP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]
2025-05-19 PID bug fix and tuning. Added status to debug menu options. Misc
    [ADC_Support.c, Debug_Port.c, Main_Support.c]
2025-05-20 Added ADC offset and ADC gain error compenstaion for +/-VS and Vmon channel 1 and 2
    [ADC_Support.c, ADC_Support.h]
2025-05-21 Updated PID K values to header file
2025-05-22 Changes to channel current calculation to account for RMS low Amp digital quantization error being larger than acceptable
    [ADC_Support.c, ADC_Support.h]
2025-05-26 Bug fix in callculation on instant Amp Current. Added calibration data for CH1 Amp Monitor. Added Fan control for Channel 1
    [ADC_Support.c, ADC_Support.h, Main_Support.c]
2025-05-27 Channel 2 operational - bug in channel 1 and 2 can not both be on or it will freeze
    [ADC_Support.c, ADC_Support.h, Debug_Port.c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]
2025-05-27 Changes to ADC3 callback so supply rails do not run every time. Changes to main screen config image size and background. Changes to set screen - no negative current values
2025-05-29 Cleanup of Simulate directory
    [ArbPwrBoost_P2.SchDoc, ArbPwrBoost_P8.SchDoc]
2025-06-02 Updated schematics to REV 3 PCB stayed at REV 4 - updated output for updated BOM
    [ArbPwrBoost.GBL, ArbPwrBoost.GBO, ArbPwrBoost.GBP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]
2025-06-03 Bug fix in channel 2 current offset. Calibration of Ch2. Updated specs in user manual. Updated FW REV
    [ADC_Support.h]
2026-04-11 Added upgraded README.md - the schematic and PCB libs also seemed out of date

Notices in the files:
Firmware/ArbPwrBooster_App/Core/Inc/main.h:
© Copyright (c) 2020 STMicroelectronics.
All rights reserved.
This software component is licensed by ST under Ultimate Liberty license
